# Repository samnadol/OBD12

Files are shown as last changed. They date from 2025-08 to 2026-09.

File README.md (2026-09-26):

# OBD12 — Hardware Handoff

OBD12 is a small OBD-II dongle. It plugs straight into a vehicle's J1962 diagnostic port and bridges the vehicle's **high-speed CAN bus (ISO 15765-4)** to **Bluetooth Low Energy** (BlueNRG-M2SP module) and to a **USB-C serial port** (FT230X). An STM32G431 runs the whole board.

| Item | Location |
|---|---|
| Schematic / PCB (KiCad 9) | `pcb/pcb.kicad_sch` (root), `pcb/usb.kicad_sch`, `pcb/can.kicad_sch`, `pcb/ble.kicad_sch`, `pcb/pcb.kicad_pcb` |
| STM32 firmware (STM32CubeIDE) | `firmware/OBD12/` (`OBD12.ioc` is the CubeMX pin config) |
| BlueNRG-M2SP network-processor image | `firmware/BLUENRG-M2SP_DTM_SPI.hex` |
| Host-side test script (USB serial) | `software/main.py` |

---

## 1. Block diagram

```
                         ┌──────────────────────── +3V3 rail ───────────────────────────┐
                         │                                                              │
 USB-C J2 ──VBUS(5V)──► U4 SPX3819 LDO ──USB_REG_OUT(3.3V)──► U5 LM66100 ─┐             │
    │                                                                     ├──► +3V3 ────┤
    │                                                                     │             │
 OBD J3 pin16 ─► D2 TVS ─► FB1 ─► +12V ─► U7 LM2842 buck ─CAN_REG_OUT(3.3V)─► U8 LM66100 ─┘  │
                                                                                        │
 USB-C D+/D- ─► U2 USBLC6 ESD ─► U3 FT230X ◄──UART 115200──► ┌───────────────┐         │
                                                             │  U1 STM32G431 │◄────────┤
 OBD J3 pin6/14 ─► D1 PESD1CAN ─► U6 TCAN337 ◄──FDCAN1─────► │  32 MHz HSE   │         │
                                                             │               │         │
                                  U9 BlueNRG-M2SP ◄──SPI1───►└───────────────┘         │
                                  (VIN via JP3) ◄───────────────────────────────────────┘
```

---

## 2. Board summary

| Parameter | Value |
|---|---|
| Board outline | ~41.8 × 39.9 mm |
| Layers | 4 layers, 1.6 mm FR4 (0.21 mm prepreg / 1.065 mm core / 0.21 mm prepreg) |
| Layer use | F.Cu signal + local pours (+12V, buck SW, CAN_REG_OUT, GND) · In1.Cu **GND plane** · In2.Cu **power plane** (+3V3 and USB_VBUS areas) · B.Cu signal |
| Passives | 0603 throughout |
| Assembly | Every BOM line has an LCSC part number (built for JLCPCB PCBA) |
| Supply inputs | Vehicle +12 V (OBD pin 16) **or** USB-C 5 V. Either one runs the whole board. |
| Logic level | **3.3 V everywhere.** Nothing on the board runs at 5 V logic. |
| MCU clock | 32 MHz crystal (HSE), SYSCLK = 32 MHz (PLL not used) |
| Regulatory | The BlueNRG-M2SP is a pre-certified module; the silkscreen carries "Contains FCC ID S9NBNRGM2SP" |

---

## 3. Power

### 3.1 Rails

| Net | Nominal | Source | Loads | Notes |
|---|---|---|---|---|
| `+12V` | 9–16 V (vehicle battery) | OBD J3 pin 16 → D2 → FB1 | U7 VIN, U7 EN | 12 V vehicles only (see TVS note). The LM2842 accepts 4.5–42 V. |
| `/usb/USB_VBUS` | 5 V | USB-C J2 VBUS | U4 IN/EN, U3 VCC, U2 VBUS | The CC pins have 5.1 kΩ pulldowns (R8, R9), so the board is a USB-C sink at default USB current. |
| `CAN_REG_OUT` | 3.31 V | U7 LM2842X buck | U8 VIN, MCU PA7 (ADC) | Max 600 mA. |
| `USB_REG_OUT` | 3.33 V | U4 SPX3819M5-L LDO | U5 VIN, U8 ~CE, MCU PA6 (ADC) | Max 500 mA. |
| `+3V3` | ~3.3 V | U5 / U8 ideal-diode OR | MCU, TCAN337, BlueNRG (via JP3), LEDs, pull-ups | LM66100: 1.5 A max, ~141 mΩ Ron. |
| `Net-(U3-3V3OUT)` | 3.3 V | FT230X internal regulator | FT230X VCCIO and ~RESET | Local to U3 only. |

### 3.2 12 V input path (sheet `can`)
- **D2 SMAJ24A**: 400 W unidirectional TVS from OBD pin 16 to GND. It has a 24 V standoff and clamps around 39 V at rated peak current. Because it would start conducting on a 24 V truck's charging voltage, the board is **12 V vehicles only**.
- **FB1 BLM18AG121SN1D**: ferrite bead that filters the input.
- **No series reverse-polarity diode.** OBD pin 16 is always battery positive in a real vehicle. On a bench supply, a reversed connection forward-biases D2 and shorts the supply.
- **U7 LM2842X**: 550 kHz, 600 mA asynchronous buck.
  - Parts: L1 15 µH (Würth WE-LQSH-3012), D3 SM5819PL Schottky catch diode, C19 100 nF bootstrap cap. EN is tied to VIN, so the buck is always on.
  - Feedback divider: R19 3.4 kΩ (top) and R20 1.02 kΩ (bottom).
  - Vout = 0.765 V × (1 + 3.4/1.02) ≈ **3.31 V**.
  - Input caps: C22 100 nF, C23 10 µF. Output caps: C20 10 µF, C21 100 nF.

### 3.3 USB input path (sheet `usb`)
- **U4 SPX3819M5-L** adjustable LDO. EN is tied to VBUS.
  - Divider: R12 56 kΩ (top) and R14 33 kΩ (bottom).
  - Vout = 1.235 V × (1 + 56/33) ≈ **3.33 V**.
  - Input caps: C10 1 µF, C11 100 nF, C12 10 µF.

### 3.4 Power OR-ing / priority (U5, U8 — LM66100 ideal diodes)
- U5 (USB side) and U8 (CAN side) both drive `+3V3`.
- **USB has priority:**
  - `USB_REG_OUT` drives U8 `~CE` directly. When USB power is present, the 12 V path is shut off.
  - U8's `ST` output (net `CAN_REG_ST`, pulled up to `CAN_REG_OUT` by R18 10 kΩ) drives U5 `~CE`.
- Both status pins go to the MCU:
  - `USB_REG_ST` (U5 ST, pulled up to +3V3 by R13 10 kΩ) → **PB6**
  - `CAN_REG_ST` (U8 ST) → **PB7**
- Both regulator outputs are also measured by ADC2: `USB_REG_OUT` → **PA6** (IN3) and `CAN_REG_OUT` → **PA7** (IN4). Firmware reports all four values over BLE (Status → Power characteristic).
- +3V3 bulk and decoupling capacitors:
  - C13 10 µF, C14 100 nF (usb sheet)
  - C16 1 µF, C17 10 µF, C24 10 µF, C25 100 nF (can sheet)
  - MCU decoupling C1–C5

### 3.5 Power indicator
- **DS1** (red, silk "PWR"): +3V3 → DS1 → R5 1.02 kΩ → GND. It stays on whenever +3V3 is up.

---

## 4. STM32G431KBT6 pin map (U1, LQFP-32)

The MCU is an STM32G431KBT6: Cortex-M4F, 128 KB flash, 32 KB RAM, running at 3.3 V.

| Pin | Port | Net (schematic) | Function / peripheral | Dir | Connected to | Notes |
|---|---|---|---|---|---|---|
| 1 | VDD | +3V3 | Supply | – | | C1–C5 decoupling |
| 2 | PF0 | SYS_OSC_IN | RCC_OSC_IN | – | Y1 pin 1, C6 12 pF | 32 MHz HSE |
| 3 | PF1 | SYS_OSC_OUT | RCC_OSC_OUT | – | Y1 pin 3, C7 12 pF | |
| 4 | PG10-NRST | SYS_NRST | Reset | I | R3 10 k pull-up, SW1 to GND, J1 pin 3 | Silk "RESET" |
| 5 | PA0 | SPI_IRQ | GPIO EXTI0 (rising) | I | JP4 → U9 DIO7 | BlueNRG IRQ |
| 6 | PA1 | BLE_NRST | GPIO out | O | U9 RESETN, J5 pin 3 | BlueNRG reset, active low |
| 7 | PA2 | FDCAN_FAULT | GPIO EXTI2 | I | U6 FAULT, R15 10 k pull-up | Transceiver fault, open-drain, active high |
| 8 | PA3 | FDCAN_SILENT | GPIO out | O | U6 S | High = silent (listen-only). Firmware drives it low. |
| 9 | PA4 | HWCONF0 | GPIO in, internal pull-down | I | R1 0 Ω (DNP) to +3V3 | HW strap bit 0 |
| 10 | PA5 | LED_STATUS_1 | GPIO out | O | DS2 anode (green, R6 1.02 k) | Silk "S1", active high |
| 11 | PA6 | USB_REG_OUT | ADC2_IN3 | AI | U4 OUT | USB LDO output monitor |
| 12 | PA7 | CAN_REG_OUT | ADC2_IN4 | AI | U7 buck output | 12 V buck output monitor |
| 13 | PB0 | LED_STATUS_2 | GPIO out | O | DS3 anode (green, R7 1.02 k) | Silk "S2", active high |
| 14 | VSSA | GND | | | | |
| 15 | VDDA | +3V3 | | | | No separate analog filtering |
| 16 | VSS | GND | | | | |
| 17 | VDD | +3V3 | | | | |
| 18 | PA8 | HWCONF1 | GPIO in, internal pull-down | I | R2 0 Ω (DNP) to +3V3 | HW strap bit 1 |
| 19 | PA9 | USB_RXD,MCU_TXD | USART1_TX | O | U3 RXD | 115200 8N1 |
| 20 | PA10 | USB_TXD,MCU_RXD | USART1_RX | I | U3 TXD | |
| 21 | PA11 | FDCAN_RX | FDCAN1_RX | I | U6 RXD | |
| 22 | PA12 | FDCAN_TX | FDCAN1_TX | O | U6 TXD | |
| 23 | PA13 | T_JTMS_SWDIO | SWDIO | IO | J1 pin 2 | |
| 24 | PA14 | T_JCLK_SWCLK | SWCLK | I | J1 pin 4 | |
| 25 | PA15 | SPI_CS | GPIO out (SPI1 CS) | O | U9 DIO11 | Active low |
| 26 | PB3 | SPI_CLK | SPI1_SCK | O | U9 DIO0 | |
| 27 | PB4 | SPI_MISO | SPI1_MISO | I | U9 DIO2 | |
| 28 | PB5 | SPI_MOSI | SPI1_MOSI | O | U9 DIO3 | |
| 29 | PB6 | USB_REG_ST | GPIO in | I | U5 ST, R13 10 k pull-up | USB-path ideal diode status |
| 30 | PB7 | CAN_REG_ST | GPIO in | I | U8 ST, U5 ~CE, R18 10 k pull-up to CAN_REG_OUT | CAN-path ideal diode status |
| 31 | PB8-BOOT0 | SYS_BOOT0 | BOOT0 | I | R4 10 k pull-down, JP1 to +3V3 | Bridge JP1 to boot the ST ROM bootloader |
| 32 | VSS | GND | | | | |

### Peripheral configuration (from `OBD12.ioc`)

| Peripheral | Settings |
|---|---|
| RCC | HSE 32 MHz crystal → SYSCLK / AHB / APB = 32 MHz. FDCAN kernel clock = HSE. |
| FDCAN1 | Classic CAN, **500 kbit/s**. Prescaler 1, Seg1 50, Seg2 13 (64 tq, sample point ≈ 79.7 %), SJW 4. Auto-retransmit off. One standard-ID range filter (0x000–0x7FF → FIFO0). |
| SPI1 | Master, 8-bit, CPOL low / CPHA 2nd edge (mode 1), prescaler 16 → 2 Mbit/s |
| USART1 | 115200 baud, 8N1, async |
| ADC2 | 12-bit, single-ended, software trigger, IN3 / IN4 |
| TIM6 / TIM7 | 1 kHz tick base (32000 prescaler). TIM6 period 1000 (1 s), TIM7 period 100 (100 ms). |
| EXTI | EXTI0 (BLE IRQ), EXTI2 (CAN fault) |

### Hardware configuration straps
- R1 (PA4 → HWCONF0) and R2 (PA8 → HWCONF1) are 0 Ω links to +3V3. Both are **DNP** by default, and the internal pull-downs read the strap as `0b00`.
- Firmware prints the strap at boot (`Hardware Configuration: 0bXY`). Silkscreen: "CONF 0 1".
- Use the straps to mark board revisions or assembly variants.

---

## 5. CAN interface (sheet `can`)

| Item | Detail |
|---|---|
| Transceiver | **U6 TCAN337** (TI), SOIC-8, 3.3 V supply (VCC = +3V3), up to 1 Mbit/s. Pin 5 = FAULT, pin 8 = S (silent). |
| Logic side | TXD/RXD at 3.3 V directly on PA12/PA11. No level shifting is needed. |
| Bus levels | ISO 11898-2 compatible. The differential is ~0 V when recessive and ≥ 1.5 V when dominant into 60 Ω. A 3.3 V transceiver works on the same bus as 5 V transceivers. |
| Bit rate | 500 kbit/s in firmware (standard OBD-II CAN rate). The hardware supports up to 1 Mbit/s classic CAN. |
| Modes | PA3 low = normal. PA3 high = silent/listen-only (TX disabled, RX still active). |
| Fault | FAULT is open-drain, pulled up by R15 10 k to +3V3, and raises EXTI2 on PA2. It flags TXD dominant timeout, thermal shutdown, and similar faults. |
| ESD | **D1 PESD1CAN**: dual-line CAN ESD/TVS (Nexperia) on CANH/CANL to GND |
| Termination | **None populated (DNP).** Optional split termination: R16 60 Ω + R17 60 Ω in series across CANH–CANL, with C18 4.7 nF from the midpoint to GND. |
| Connector pins | CANH → J3 pin 6, CANL → J3 pin 14 |

**Termination guidance**
- **In a vehicle: leave R16, R17, and C18 unpopulated.** The OBD port is a stub off an already-terminated bus (two 120 Ω ends = 60 Ω). Adding a third terminator loads the bus.
- **On the bench** with only one other node: fit R16/R17 (60 Ω; 60.4 Ω 1 % is fine) and C18 4.7 nF to get split termination. The other end still needs its own 120 Ω.
- Measure CANH–CANL with the vehicle off. You should see ~60 Ω from the vehicle side alone.

### OBD-II connector (J3, Comtech C-OBD-II-16M, male J1962 plug)

| J3 pin | Standard use | Board net | Connected? |
|---|---|---|---|
| 2 | SAE J1850 bus + | `OBD_J1850+` | Labelled only, no circuitry |
| 4 | Chassis ground | `OBD_CGND` → J4 pin 1 | Only through **J4 (DNP)**. Fit a jumper/short on J4 to tie chassis GND to board GND. |
| 5 | Signal ground | GND | Yes (board ground reference) |
| 6 | CAN high (ISO 15765) | `CAN_T+` | Yes → U6 CANH |
| 7 | ISO 9141/14230 K-line | `OBD_1941-2K` | Labelled only, no circuitry |
| 10 | SAE J1850 bus − | `OBD_J1850-` | Labelled only, no circuitry |
| 14 | CAN low (ISO 15765) | `CAN_T-` | Yes → U6 CANL |
| 15 | ISO 9141/14230 L-line | `OBD_1941-2L` | Labelled only, no circuitry |
| 16 | Battery + (unswitched) | +12V (via D2/FB1) | Yes |
| 1, 3, 8, 9, 11, 12, 13 | OEM-specific | – | Not connected |

Only CAN (ISO 15765-4) is implemented. The J1850, K-line, and L-line pins are broken out to named nets for a future revision.

---

## 6. Bluetooth LE (sheet `ble`)

| Item | Detail |
|---|---|
| Module | **U9 ST BlueNRG-M2SP**: BlueNRG-2 SoC with integrated chip antenna, pre-certified, used as an SPI network processor |
| Firmware on module | `firmware/BLUENRG-M2SP_DTM_SPI.hex` (ST DTM image, SPI transport). Flash it once through J5. |
| Supply | VIN from +3V3 through **JP3 "BLE_3V3_ISO"** (solder jumper, bridged by default). Decoupling: C26 100 nF, C27 1 µF, C28 10 µF. Cut JP3 to isolate or measure module current. |
| Host link | SPI1 at 2 Mbit/s, mode 1 |

**MCU ↔ module wiring**

| Signal | STM32 | BlueNRG-M2SP |
|---|---|---|
| SPI_CLK | PB3 | DIO0 (pin 15) |
| SPI_MISO | PB4 | DIO2 (pin 16) |
| SPI_MOSI | PB5 | DIO3 (pin 17) |
| SPI_CS | PA15 | DIO11 (pin 11) |
| SPI_IRQ | PA0 | DIO7/BOOT (pin 7), through JP4 |
| RESET | PA1 | RESETN (pin 19) |
| SWDIO / SWCLK | – | DIO10 (pin 13) / DIO9 (pin 12) → J5 |

**Boot / IRQ jumpers.** DIO7 is both the module's SPI IRQ output and its bootloader-select pin.

| Jumper | Silk | Default | Purpose |
|---|---|---|---|
| JP4 | BLE BOOT ISO | Bridged | Connects DIO7 to MCU PA0 (normal operation) |
| JP2 | BLE_BOOT 1 | Open | Ties DIO7 to +3V3 (force the module's bootloader at reset) |
| JP5 | BLE_BOOT 0 | Open | Ties DIO7 to GND |
| JP3 | BLE_3V3_ISO | Bridged | Module VIN from +3V3 |

**Firmware BLE profile (for reference).** The module advertises at 250–500 ms intervals (0.625 ms units: 400–800) and exposes three services:
- Device Information
- Nordic-UART-style RX/TX service
- Status service with a Power characteristic carrying the regulator ST bits and ADC readings

---

## 7. USB-C / debug UART (sheet `usb`)

| Item | Detail |
|---|---|
| Connector | **J2** USB-C receptacle (G-Switch GT-USB-7010ASV), USB 2.0 only |
| CC | R8, R9 5.1 kΩ to GND on CC1 and CC2 → default-current sink |
| ESD | **U2 USBLC6-2SC6** on D+/D−, VBUS-referenced |
| Bridge | **U3 FTDI FT230XS**. VCC = VBUS (5 V). The internal 3V3OUT feeds VCCIO, so the UART is **3.3 V**. RTS is looped to CTS. |
| UART | FT230X TXD → PA10 (USART1_RX) and PA9 (USART1_TX) → FT230X RXD, 115200 8N1 |
| LEDs | DS4 (RX) on CBUS1 and DS5 (TX) on CBUS2, both green. Each LED is fed from +3V3 through R10/R11 60 Ω, with the cathode sunk by CBUS. Silk "TX RX". |
| USB IDs | VID 0x0403 / PID 0x6015 (FT230X default). `software/main.py` finds the board by an FTDI serial number starting with `OBD12_`, so **program each FT230X EEPROM with FT_PROG** to set that serial. |

FT230X decoupling: C8 100 nF + C9 1 µF on 3V3OUT, C10–C12 on VBUS.

---

## 8. Programming & debug connectors

Both programming headers are Tag-Connect **TC2030-NL** (no-legs) footprints and use a TC2030-NL cable with a standard 10-pin Cortex adapter.

| Ref | Target | Pin 1 | Pin 2 | Pin 3 | Pin 4 | Pin 5 | Pin 6 |
|---|---|---|---|---|---|---|---|
| J1 | STM32 (U1) | +3V3 (VTref) | SWDIO (PA13) | NRST | SWCLK (PA14) | GND | SWO (NC) |
| J5 | BlueNRG-M2SP (U9) | +3V3 | DIO10 (SWDIO) | RESETN (shared with PA1) | DIO9 (SWCLK) | GND | NC |

**The board must be powered (USB or 12 V) while programming.** Pin 1 is a voltage reference, not a supply input.

Other user controls:
- **SW1** (silk "RESET"): tactile switch that pulls the STM32 NRST low.
- **JP1** (silk "BOOT0 PB8"): open solder jumper. Bridge it to hold BOOT0 high and enter the STM32 system bootloader (USART1 is reachable through the FT230X).

---

## 9. LEDs

| Ref | Colour | Silk | Driven by | Series R | Meaning |
|---|---|---|---|---|---|
| DS1 | Red | PWR | +3V3 | R5 1.02 k | +3V3 present |
| DS2 | Green | S1 | PA5, active high | R6 1.02 k | Firmware status 1 (heartbeat / app state) |
| DS3 | Green | S2 | PB0, active high | R7 1.02 k | Firmware status 2 |
| DS4 | Green | RX | FT230X CBUS1, active low | R10 60 Ω | USB UART RX activity |
| DS5 | Green | TX | FT230X CBUS2, active low | R11 60 Ω | USB UART TX activity |

---

## 10. Bill of materials

This is the populated BOM, generated from the schematic. LCSC numbers come from the `LCSC` field.

| Refs | Qty | Value / part | Package | LCSC | Description |
|---|---|---|---|---|---|
| U1 | 1 | STM32G431KBT6 | LQFP-32 | C5270317 | MCU, Cortex-M4F, 128 KB / 32 KB |
| U2 | 1 | USBLC6-2SC6 | SOT-23-6 | C7519 | USB ESD protection |
| U3 | 1 | FT230XS | SSOP-16 | C69082 | USB ↔ UART bridge |
| U4 | 1 | SPX3819M5-L | SOT-23-5 | C9056 | 500 mA adjustable LDO (USB → 3.3 V) |
| U5, U8 | 2 | LM66100DCK | SC-70-6 | C2869734 | Ideal diode (power OR-ing) |
| U6 | 1 | TCAN337 | SOIC-8 | C2860648 | 3.3 V CAN transceiver with silent mode and fault output |
| U7 | 1 | LM2842X | TSOT-23-6 | C2865947 | 42 V / 600 mA buck (12 V → 3.3 V) |
| U9 | 1 | BLUENRG-M2SP | module | C1850403 | BLE 5 module (SPI) |
| Y1 | 1 | Würth 830103622909 | 3225-4 | C9009 | Crystal (32 MHz HSE per firmware config) |
| D1 | 1 | PESD1CAN | SOT-23 | C15771 | CAN bus ESD |
| D2 | 1 | SMAJ24A | SMA | C113962 | 24 V TVS on +12 V input |
| D3 | 1 | SM5819PL-TP | SOD-123F | C669023 | Buck catch Schottky |
| L1 | 1 | 15 µH WE-LQSH-3012 | 3×3 mm | C668450 | Buck inductor |
| FB1 | 1 | BLM18AG121SN1D | 0603 | C76892 | Ferrite bead, 12 V input |
| J2 | 1 | USB-C 16P (GT-USB-7010ASV) | SMD | C2988369 | USB 2.0 Type-C receptacle |
| J3 | 1 | Comtech C-OBD-II-16M | – | – | OBD-II J1962 male plug |
| J1, J5 | 2 | TC2030-NL | footprint | – | SWD Tag-Connect pads (no part) |
| SW1 | 1 | TS-1187A | SMD | C318884 | Reset button |
| DS1 | 1 | Red LED | 0603 | C965799 | Power |
| DS2–DS5 | 4 | Green LED | 0603 | C965804 | Status / USB activity |
| C2–C4, C8, C11, C14, C15, C19, C21, C22, C25, C26 | 12 | 100 nF | 0603 | C14663 | Decoupling / bootstrap |
| C1, C9, C10, C16, C27 | 5 | 1 µF | 0603 | C559769 | Decoupling |
| C5, C12, C13, C17, C20, C23, C24, C28 | 8 | 10 µF | 0603 | C92487 | Bulk |
| C6, C7 | 2 | 12 pF | 0603 | C107034 | Crystal load |
| R3, R4, R13, R15, R18 | 5 | 10 k | 0603 | C25804 | Pull-ups / pull-downs |
| R5–R7, R20 | 4 | 1.02 k | 0603 | C22831 | LED resistors, buck FB bottom |
| R8, R9 | 2 | 5.1 k | 0603 | C23186 | USB-C CC pulldowns |
| R10, R11 | 2 | 60 Ω | 0603 | C166918 | FT230X LED resistors |
| R12 | 1 | 56 k | 0603 | C23206 | LDO ADJ top |
| R14 | 1 | 33 k | 0603 | C4216 | LDO ADJ bottom |
| R19 | 1 | 3.4 k | 0603 | C22997 | Buck FB top |
| JP1–JP5 | 5 | Solder jumpers | – | – | JP3 and JP4 bridged by default; JP1, JP2, JP5 open |
| G1 | 1 | Logo | – | – | Silkscreen |

**DNP (do not populate) by default**

| Ref | Value | Purpose |
|---|---|---|
| R1, R2 | 0 Ω | HWCONF0/1 straps |
| R16, R17 | 60 Ω | CAN split termination |
| C18 | 4.7 nF | CAN split-termination midpoint cap |
| J4 | 1×2 2.54 mm header | Links OBD chassis ground (pin 4) to board GND |

---

## 11. Bring-up checklist

1. **Power, USB only.**
   - `USB_REG_OUT` ≈ 3.33 V and `+3V3` ≈ 3.3 V. DS1 lights.
   - FT230X enumerates (0403:6015).
2. **Power, 12 V only** (current-limited bench supply on J3 pins 16 and 5):
   - `CAN_REG_OUT` ≈ 3.31 V and `+3V3` up.
   - Check the buck switch node `/can/SW` for clean 550 kHz switching.
3. **Both supplies connected.**
   - `+3V3` must stay up with no glitch when either source is added or removed.
   - PB6/PB7 read back the expected status. See review note 2 below.
4. **Program the STM32** over J1 (SWD) and program the **BlueNRG-M2SP** over J5 with `BLUENRG-M2SP_DTM_SPI.hex`.
5. **Program the FT230X EEPROM** so its serial number starts with `OBD12_`.
6. **Check the UART console** at 115200 8N1. The boot banner shows the HWCONF strap and the STM32 UID.
7. **Check CAN.**
   - On the bench, fit the termination or use a terminated CAN adapter at 500 kbit/s.
   - In a vehicle, the firmware requests the VIN (Mode 09 PID 02) at start-up.
   - PA2 FAULT must stay low.
8. **Check BLE.** The module advertises, and the Nordic UART and Status services are visible from a phone.

---

## 12. Design review notes / open items

These came up while documenting the design. **Check each one before the next spin.**

1. **U4 SPX3819 has no output capacitor on `USB_REG_OUT`.**
   - The LDO needs ≥ 1 µF on its output to be stable.
   - The 10 µF parts (C13, C17, C24) sit on `+3V3`, *behind* the LM66100 ideal diode.
   - Add ~1–10 µF directly on `USB_REG_OUT`. The buck side already has C20/C21.
2. **Power-priority logic depends on the LM66100 `ST` polarity.**
   - With USB present, U8 is disabled, and U5's `~CE` is driven by U8's `ST` pin (pulled up to `CAN_REG_OUT` by R18).
   - If `ST` goes high-Z while U8 is disabled, R18 pulls U5 `~CE` high and **both paths turn off when USB and 12 V are both present.**
   - Verify on hardware (checklist step 3) and against the LM66100 datasheet.
3. **ADC monitoring of the 3.3 V rails.**
   - `USB_REG_OUT` and `CAN_REG_OUT` (~3.31–3.33 V) go straight to PA6/PA7 while VDDA = `+3V3`, which is slightly lower after the ideal-diode drop.
   - The readings will sit at or near full scale (4095), so they only work as presence detectors.
   - Add a divider (for example 2:1) if real voltage measurement is wanted. The ADC pin also sees more than VDDA when that rail is backed by the other source.
4. **Voltage rating of C23 (10 µF, 0603, LCSC C92487) on the +12 V rail.**
   - Confirm the rated voltage is at least 25 V, and preferably 50 V, for automotive transients up to the TVS clamp (~39 V).
   - Also account for DC-bias derating: a 0603 10 µF part at 12 V keeps only a small fraction of its nominal capacitance.
   - C22 (100 nF, C14663) is 50 V.
5. **FT230X LED resistors R10/R11 = 60 Ω.**
   - That gives roughly 15–20 mA per LED, above the FT230X CBUS default drive strength.
   - Consider ~1 k, or configure CBUS drive in the EEPROM.
6. **FT230X back-powering.** When the board runs on 12 V only, the MCU's TX (PA9) drives the RXD pin of the unpowered FT230X. A series resistor on PA9 would limit that current.
7. **U9 pad 21 (GND) shows as unconnected in the netlist.** Only pad 8 is tied to GND. Check the footprint against the BlueNRG-M2SP datasheet and ground every GND pad.
8. **No reverse-polarity protection on the 12 V input.** This is acceptable for a J1962 port but not for a bench supply. A series Schottky or a P-FET would protect it.
9. **VDDA is tied directly to +3V3.** There is no ferrite or RC filter, which is acceptable for the current coarse ADC use.
10. Items carried over from the previous README:
    - Add an activity/status LED for the BlueNRG-M2SP, driven by the DTM firmware.
    - Add 10–100 k pull-down resistors on each regulator output so the outputs don't float when that source is unpowered. This partly overlaps item 1. `USB_REG_OUT` already has R12+R14 (89 k).
    - Future: move from the M2SP module to a bare BlueNRG-2 with a direct antenna.

### Firmware TODO (carried over)
- CAN peripheral enable and setup. The FDCAN init, filter, and RX path now exist in `Core/Src/CAN/`.
- OBD layer (`Core/Src/CAN/OBD.c`, `ISOTP.c`)
- BLE and UART transport layers
- App protocol layer

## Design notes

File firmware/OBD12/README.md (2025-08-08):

TX Power Settings:
	 0: -14 dBm
	 1: -11 dBm
	 2: -8 dBm
	 3: -5 dBm
	 4: -2 dBm
	 5: 2 dBm
	 6: 4 dBm
	 7: 8 dBm

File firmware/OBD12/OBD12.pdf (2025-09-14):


19/08/2025

OBD12 Project
Configuration Report

## 1. Description

### 1.1. Project

Project Name | OBD12
Board Name | custom
Generated with: | STM32CubeMX 6.15.0
Date | 08/19/2025

### 1.2. MCU

MCU Series | STM32G4
MCU Line | STM32G4x1
MCU name | STM32G431KBTx
MCU Package | LQFP32
MCU Pin number | 32

### 1.3. Core(s) information

Core(s) | ARM Cortex-M4

## 2. Pinout Configuration

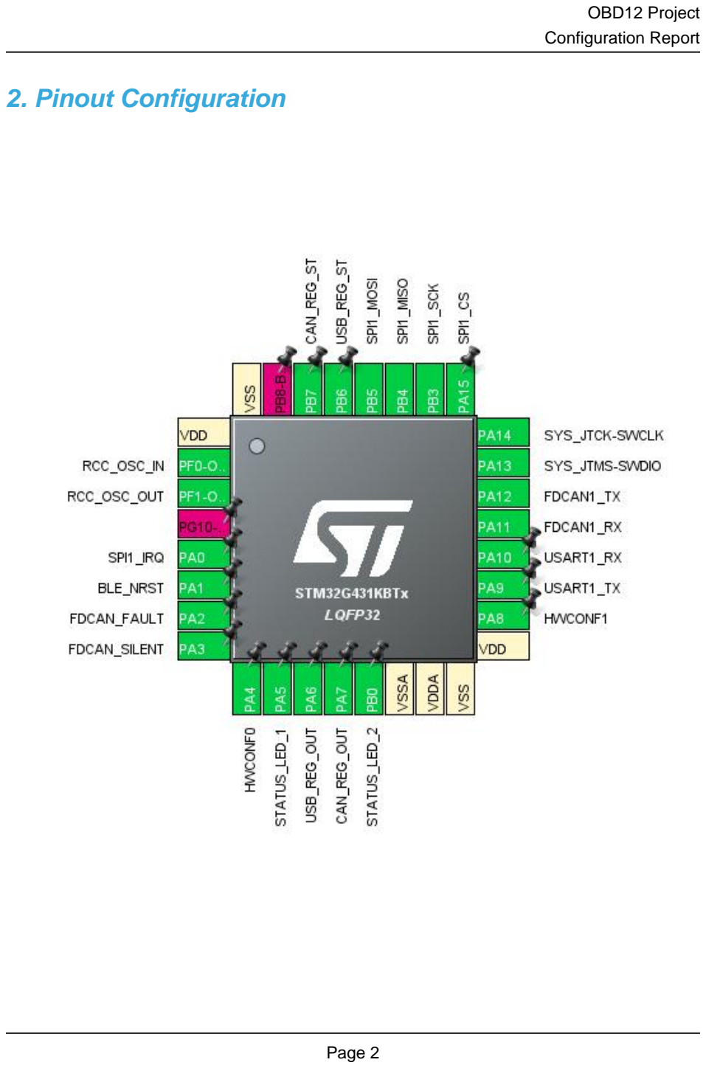
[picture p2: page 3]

## 3. Pins Configuration

Pin Number LQFP32 | Pin Name (function after reset) | Pin Type | Alternate Function(s) | Label
1 | VDD | Power
2 | PF0-OSC_IN | I/O | RCC_OSC_IN
3 | PF1-OSC_OUT | I/O | RCC_OSC_OUT
4 | PG10-NRST | I/O
5 | PA0 | I/O | GPIO_EXTI0 | SPI1_IRQ
6 | PA1 * | I/O | GPIO_Output | BLE_NRST
7 | PA2 | I/O | GPIO_EXTI2 | FDCAN_FAULT
8 | PA3 * | I/O | GPIO_Output | FDCAN_SILENT
9 | PA4 * | I/O | GPIO_Input | HWCONF0
10 | PA5 * | I/O | GPIO_Output | STATUS_LED_1
11 | PA6 | I/O | ADC2_IN3 | USB_REG_OUT
12 | PA7 | I/O | ADC2_IN4 | CAN_REG_OUT
13 | PB0 * | I/O | GPIO_Output | STATUS_LED_2
14 | VSSA | Power
15 | VDDA | Power
16 | VSS | Power
17 | VDD | Power
18 | PA8 * | I/O | GPIO_Input | HWCONF1
19 | PA9 | I/O | USART1_TX
20 | PA10 | I/O | USART1_RX
21 | PA11 | I/O | FDCAN1_RX
22 | PA12 | I/O | FDCAN1_TX
23 | PA13 | I/O | SYS_JTMS-SWDIO
24 | PA14 | I/O | SYS_JTCK-SWCLK
25 | PA15 * | I/O | GPIO_Output | SPI1_CS
26 | PB3 | I/O | SPI1_SCK
27 | PB4 | I/O | SPI1_MISO
28 | PB5 | I/O | SPI1_MOSI
29 | PB6 * | I/O | GPIO_Input | USB_REG_ST
30 | PB7 * | I/O | GPIO_Input | CAN_REG_ST
31 | PB8-BOOT0 | I/O
32 | VSS | Power

* The pin is affected with an I/O function

## 4. Clock Tree Configuration

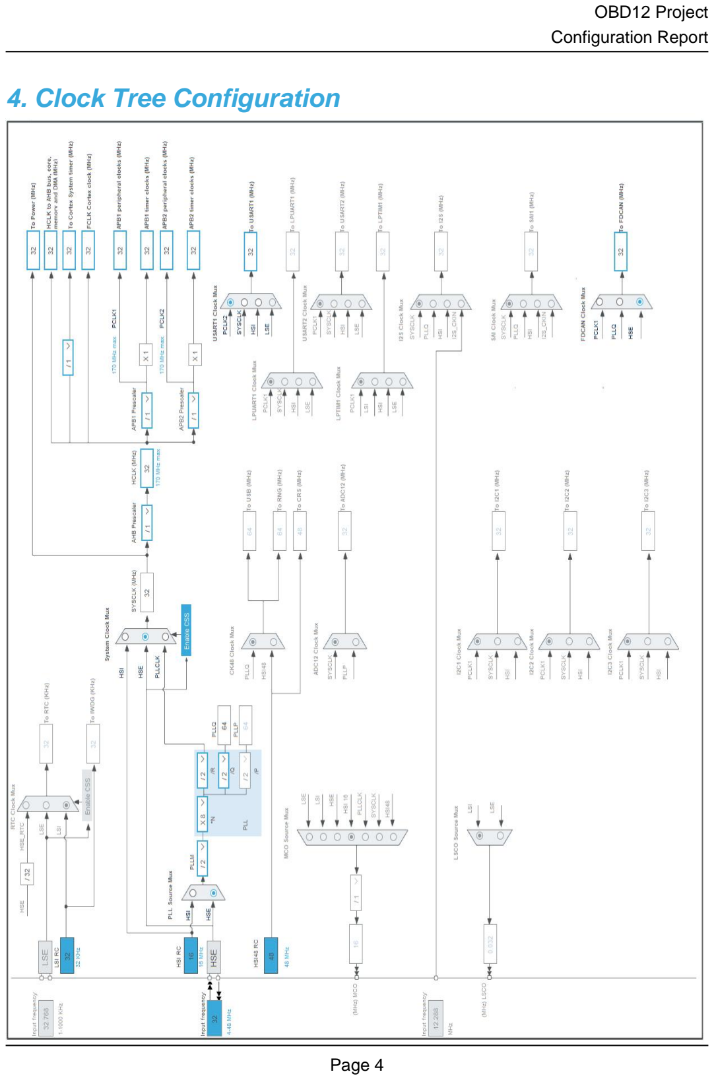
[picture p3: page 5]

## 1. Power Consumption Calculator report

### 1.1. Microcontroller Selection

Series | STM32G4
Line | STM32G4x1
MCU | STM32G431KBTx
Datasheet | DS12589_Rev0

### 1.2. Parameter Selection

Temperature | 25
Vdd | 3.0

### 1.3. Battery Selection

Battery | Li-SOCL2(A3400)
Capacity | 3400.0 mAh
Self Discharge | 0.08 %/month
Nominal Voltage | 3.6 V
Max Cont Current | 100.0 mA
Max Pulse Current | 200.0 mA
Cells in series | 1
Cells in parallel | 1

### 1.4. Sequence

Step | Step1 | Step2
Mode | RUN | STOP1
Vdd | 3.0 | 3.0
Voltage Source | Battery | Battery
Range | Range1-Boost | NoRange
Fetch Type | FLASH/ART | NA
CPU Frequency | 170 MHz | 0 Hz
Clock Configuration | HSE BYP PLL | ALL CLOCKS OFF
Clock Source Frequency | 4 MHz | 0 Hz
Peripherals
Additional Cons. | 0 mA | 0 mA
Average Current | 25.5 mA | 59 µA
Duration | 0.1 ms | 0.9 ms
DMIPS | 213.0 | 0.0
Ta Max | 124.19 | 129.99
Category | In DS Table | In DS Table

### 1.5. Results

Sequence Time | 1 ms | Average Current | 2.6 mA
Battery Life | 1 month, 23 days, 22 hours | Average DMIPS | 212.5 DMIPS

### 1.6. Chart

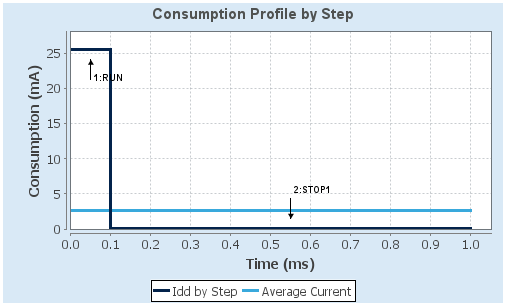
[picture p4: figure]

## 2. Software Project

### 2.1. Project Settings

Name | Value
Project Name | OBD12
Project Folder | C:\Users\samna\Desktop\OBD12\firmware\OBD12
Toolchain / IDE | STM32CubeIDE
Firmware Package Name and Version | STM32Cube FW_G4 V1.6.1
Application Structure | Advanced
Generate Under Root | Yes
Do not generate the main() | No
Minimum Heap Size | 0x200
Minimum Stack Size | 0x400

### 2.2. Code Generation Settings

Name | Value
STM32Cube MCU packages and embedded software | Copy only the necessary library files
Generate peripheral initialization as a pair of '.c/.h' files | No
Backup previously generated files when re-generating | No
Keep User Code when re-generating | Yes
Delete previously generated files when not re-generated | Yes
Set all free pins as analog (to optimize the power consumption) | No
Enable Full Assert | No

### 2.3. Advanced Settings - Generated Function Calls

Rank | Function Name | Peripheral Instance Name
1 | SystemClock_Config | RCC
2 | MX_GPIO_Init | GPIO
3 | MX_ADC2_Init | ADC2
4 | MX_USART1_UART_Init | USART1
5 | MX_FDCAN1_Init | FDCAN1
6 | MX_TIM6_Init | TIM6
7 | MX_TIM7_Init | TIM7

## 3. Peripherals and Middlewares Configuration

### 3.1. ADC2

IN3: IN3 Single-ended
mode: IN4
3.1.1. Parameter Settings:

ADCs_Common_Settings:

Mode | Independent mode
ADC_Settings:
Clock Prescaler | Synchronous clock mode divided by 2
Resolution | ADC 12-bit resolution
Data Alignment | Right alignment
Gain Compensation | 0
Scan Conversion Mode | Disabled
End Of Conversion Selection | End of single conversion
Low Power Auto Wait | Disabled
Continuous Conversion Mode | Disabled
Discontinuous Conversion Mode | Disabled
DMA Continuous Requests | Disabled
Overrun behaviour | Overrun data preserved
ADC_Regular_ConversionMode:
Enable Regular Conversions | Enable
Enable Regular Oversampling | Disable
Number Of Conversion | 1
External Trigger Conversion Source | Regular Conversion launched by software
External Trigger Conversion Edge | None
Rank | 1
Channel | Channel 3
Sampling Time | 2.5 Cycles
Offset Number | No offset
ADC_Injected_ConversionMode:
Enable Injected Conversions | Disable
Analog Watchdog 1:
Enable Analog WatchDog1 Mode | false
Analog Watchdog 2:
Enable Analog WatchDog2 Mode | false
Analog Watchdog 3:
Enable Analog WatchDog3 Mode | false

### 3.2. FDCAN1

mode: Activated
3.2.1. Parameter Settings:

Basic Parameters:

Clock Divider | Divide kernel clock by 1
Frame Format | Classic mode
Mode | Normal mode
Auto Retransmission | Disable
Transmit Pause | Disable
Protocol Exception | Disable
Nominal Sync Jump Width | 4 *
Data Prescaler | 1
Data Sync Jump Width | 1
Data Time Seg1 | 1
Data Time Seg2 | 1
Std Filters Nbr | 1 *
Ext Filters Nbr | 0
Tx Fifo Queue Mode | FIFO mode
Bit Timings Parameters:
Nominal Prescaler | 1 *
Nominal Time Quantum | 31.25 *
Nominal Time Seg1 | 50 *
Nominal Time Seg2 | 13 *
Nominal Time for one Bit | 2000 *
Nominal Baud Rate | 500000 *

### 3.3. RCC

High Speed Clock (HSE): Crystal/Ceramic Resonator
3.3.1. Parameter Settings:

System Parameters:

VDD voltage (V) | 3.3
Instruction Cache | Enabled
Prefetch Buffer | Disabled

Data Cache | Enabled
Flash Latency(WS) | 1 WS (2 CPU cycle)
RCC Parameters:
HSI Calibration Value | 64
HSE Startup Timout Value (ms) | 100
LSE Startup Timout Value (ms) | 5000
Power Parameters:
Power Regulator Voltage Scale | Power Regulator Voltage Scale 1
Peripherals Clock Configuration:
Generate the peripherals clock configuration | TRUE

### 3.4. SPI1

Mode: Full-Duplex Master
3.4.1. Parameter Settings:

Basic Parameters:

Frame Format | Motorola
Data Size | 8 Bits *
First Bit | MSB First
Clock Parameters:
Prescaler (for Baud Rate) | 16 *
Baud Rate | 2.0 MBits/s *
Clock Polarity (CPOL) | Low
Clock Phase (CPHA) | 2 Edge *
Advanced Parameters:
CRC Calculation | Disabled
NSS Signal Type | Software

### 3.5. SYS

Debug: Serial Wire
Timebase Source: SysTick
mode: save power of non-active UCPD - deactive Dead Battery pull-up

### 3.6. TIM6

mode: Activated

3.6.1. Parameter Settings:

Counter Settings:

Prescaler (PSC - 16 bits value) | 32000 - 1 *
Counter Mode | Up
Dithering | Disable
Counter Period (AutoReload Register - 16 bits value ) | 1000 - 1 *
auto-reload preload | Disable
Trigger Output (TRGO) Parameters:
Trigger Event Selection | Reset (UG bit from TIMx_EGR)

### 3.7. TIM7

mode: Activated
3.7.1. Parameter Settings:

Counter Settings:

Prescaler (PSC - 16 bits value) | 32000 - 1 *
Counter Mode | Up
Dithering | Disable
Counter Period (AutoReload Register - 16 bits value ) | 100 - 1 *
auto-reload preload | Disable
Trigger Output (TRGO) Parameters:
Trigger Event Selection | Reset (UG bit from TIMx_EGR)

### 3.8. USART1

Mode: Asynchronous
3.8.1. Parameter Settings:

Basic Parameters:

Baud Rate | 115200
Word Length | 8 Bits (including Parity)
Parity | None
Stop Bits | 1
Advanced Parameters:
Data Direction | Receive and Transmit
Over Sampling | 16 Samples

Single Sample | Disable
ClockPrescaler | 1
Fifo Mode | Disable
Txfifo Threshold | 1 eighth full configuration
Rxfifo Threshold | 1 eighth full configuration
Advanced Features:
Auto Baudrate | Disable
TX Pin Active Level Inversion | Disable
RX Pin Active Level Inversion | Disable
Data Inversion | Disable
TX and RX Pins Swapping | Disable
Overrun | Enable
DMA on RX Error | Enable
MSB First | Disable

### 3.9. STMicroelectronics.X-CUBE-BLE2.3.3.0

mode: WirelessJjBlueNRGAa2
3.9.1. Parameter Settings:

Log & Debug:
BLE2_DEBUG | 1: Only User messages are shown *
PRINT_CSV_FORMAT | 0: .csv format message print disabled
BLUENRG2_DEBUG | 0: No debug message
Basic Parameters:
HCI_READ_PACKET_SIZE | 128
HCI_MAX_PAYLOAD_SIZE | 128
HCI_READ_PACKET_NUM_MAX | 10
Connection Parameters (for expert users):
Scan Interval (SCAN_P) | 16384
Scan Window (SCAN_L) | 16384
Supervision Timeout (SUPERV_TIMEOUT) | 60
Min Connection Period (CONN_P1) | 40
Max Connection Period (CONN_P2) | 40
Min Connection Length (CONN_L1) | 2000
Max Connection Length (CONN_L2) | 2000
Advertising Type (ADV_DATA_TYPE) | Connectable Undirected Advertising (ADV_IND)
Min Advertising Interval (ADV_INTERV_MIN) | 400 *
Max Advertising Interval (ADV_INTERV_MAX) | 800 *

Min Connection Event Interval (L2CAP_INTERV_MIN) | 9
Max Connection Event Interval (L2CAP_INTERV_MAX) | 20
Timeout Multiplier (L2CAP_TIMEOUT_MULTIPLIER) | 600
3.9.2. Platform Settings:
Exti Line | PA0
BUS IO driver | SPI1
CS Line | PA15
Reset Line | PA1

* User modified value

## 4. System Configuration

### 4.1. GPIO configuration

IP | Pin | Signal | GPIO mode | GPIO pull/up pull down | Max Speed | User Label
ADC2 | PA6 | ADC2_IN3 | Analog mode | Pull-down * | n/a | USB_REG_OUT
| PA7 | ADC2_IN4 | Analog mode | Pull-down * | n/a | CAN_REG_OUT
FDCAN1 | PA11 | FDCAN1_RX | Alternate Function Push Pull | No pull-up and no pull-down | High *
| PA12 | FDCAN1_TX | Alternate Function Push Pull | No pull-up and no pull-down | High *
RCC | PF0-OSC_IN | RCC_OSC_IN | n/a | n/a | n/a
| PF1-OSC_OUT | RCC_OSC_OUT | n/a | n/a | n/a
SPI1 | PB3 | SPI1_SCK | Alternate Function Push Pull | No pull-up and no pull-down | Medium *
| PB4 | SPI1_MISO | Alternate Function Push Pull | No pull-up and no pull-down | Medium *
| PB5 | SPI1_MOSI | Alternate Function Push Pull | No pull-up and no pull-down | Medium *
SYS | PA13 | SYS_JTMS-SWDIO | n/a | n/a | n/a
| PA14 | SYS_JTCK-SWCLK | n/a | n/a | n/a
USART1 | PA9 | USART1_TX | Alternate Function Push Pull | No pull-up and no pull-down | Medium *
| PA10 | USART1_RX | Alternate Function Push Pull | No pull-up and no pull-down | Medium *
GPIO | PA0 | GPIO_EXTI0 | External Interrupt Mode with Rising edge trigger detection | No pull-up and no pull-down | n/a | SPI1_IRQ
| PA1 | GPIO_Output | Output Push Pull | No pull-up and no pull-down | Low | BLE_NRST
| PA2 | GPIO_EXTI2 | External Interrupt Mode with Rising edge trigger detection | No pull-up and no pull-down | n/a | FDCAN_FAULT
| PA3 | GPIO_Output | Output Push Pull | No pull-up and no pull-down | Low | FDCAN_SILENT
| PA4 | GPIO_Input | Input mode | Pull-down * | n/a | HWCONF0
| PA5 | GPIO_Output | Output Push Pull | No pull-up and no pull-down | Low | STATUS_LED_1
| PB0 | GPIO_Output | Output Push Pull | No pull-up and no pull-down | Low | STATUS_LED_2
| PA8 | GPIO_Input | Input mode | Pull-down * | n/a | HWCONF1
| PA15 | GPIO_Output | Output Push Pull | No pull-up and no pull-down | Low | SPI1_CS
| PB6 | GPIO_Input | Input mode | No pull-up and no pull-down | n/a | USB_REG_ST
| PB7 | GPIO_Input | Input mode | No pull-up and no pull-down | n/a | CAN_REG_ST

### 4.2. DMA configuration

nothing configured in DMA service

### 4.3. NVIC configuration

4.3.1. NVIC
Interrupt Table | Enable | Preenmption Priority | SubPriority
Non maskable interrupt | true | 0 | 0
Hard fault interrupt | true | 0 | 0
Memory management fault | true | 0 | 0
Prefetch fault, memory access fault | true | 0 | 0
Undefined instruction or illegal state | true | 0 | 0
System service call via SWI instruction | true | 0 | 0
Debug monitor | true | 0 | 0
Pendable request for system service | true | 0 | 0
System tick timer | true | 0 | 0
EXTI line0 interrupt | true | 1 | 0
EXTI line2 interrupt | true | 1 | 0
FDCAN1 interrupt 0 | true | 1 | 0
TIM6 global interrupt, DAC1 and DAC3 channel underrun error interrupts | true | 2 | 0
TIM7 global interrupt | true | 0 | 0
PVD/PVM1/PVM2/PVM3/PVM4 interrupts through EXTI lines 16/38/39/40/41 | unused
Flash global interrupt | unused
RCC global interrupt | unused
ADC1 and ADC2 global interrupt | unused
FDCAN1 interrupt 1 | unused
SPI1 global interrupt | unused
USART1 global interrupt / USART1 wake-up interrupt through EXTI line 25 | unused
FPU global interrupt | unused
4.3.2. NVIC Code generation
Enabled interrupt Table | Select for init sequence ordering | Generate IRQ handler | Call HAL handler
Non maskable interrupt | false | true | false
Hard fault interrupt | false | true | false
Memory management fault | false | true | false
Prefetch fault, memory access fault | false | true | false
Undefined instruction or illegal state | false | true | false
System service call via SWI instruction | false | true | false
Debug monitor | false | true | false
Pendable request for system service | false | true | false
System tick timer | false | true | true

Enabled interrupt Table | Select for init sequence ordering | Generate IRQ handler | Call HAL handler
EXTI line0 interrupt | false | true | true
EXTI line2 interrupt | false | true | true
FDCAN1 interrupt 0 | false | true | true
TIM6 global interrupt, DAC1 and DAC3 channel underrun error interrupts | false | true | true
TIM7 global interrupt | false | true | true

* User modified value

## 5. System Views

5.1. Category view
5.1.1. Current

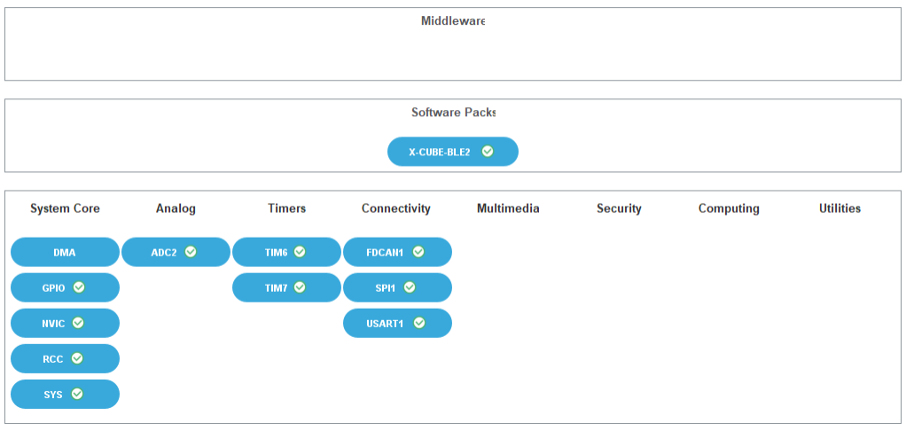
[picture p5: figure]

## 6. Software Pack Report

### 6.1. Software Pack selected

Vendor | Name | Version | Component
STMicroelectronic s | X-CUBE-BLE2 | 3.3.0 | Class : Wireless Group : BlueNRG-2 SubGroup : Controller Version : 3.3.0 Class : Wireless Group : BlueNRG-2 SubGroup : HCI_TL Variant : Basic Version : 3.3.0 Class : Wireless Group : BlueNRG-2 SubGroup : HCI_TL_INTERF ACE Variant : UserBoard Version : 3.3.0 Class : Wireless Group : BlueNRG-2 SubGroup : Utils Version : 3.3.0

## 7. Docs & Resources

Type | Link
BSDL files | https://www.st.com/resource/en/bsdl_model/stm32g4_bsdl.zip
IBIS models | https://www.st.com/resource/en/ibis_model/stm32g4_ibis.zip
System View Description | https://www.st.com/resource/en/svd/stm32g4_svd.zip
Presentations | https://www.st.com/resource/en/product_presentation/stm32-stm8_embedded_software_solutions.pdf
Presentations | https://www.st.com/resource/en/product_presentation/stm32_eval-tools_portfolio.pdf
Presentations | https://www.st.com/resource/en/product_presentation/stm32_stm8_functi onal-safety-packages.pdf
Presentations | https://www.st.com/resource/en/product_presentation/stm32-usb-c-pd-solutions-presentation.pdf
Presentations | https://www.st.com/resource/en/product_presentation/stm32-stm8_software_development_tools.pdf
Presentations | https://www.st.com/resource/en/product_presentation/microcontrollers-stm32-family-overview.pdf
Presentations | https://www.st.com/resource/en/product_presentation/microcontrollers-stm32g4-series-product-overview.pdf
Brochures | https://www.st.com/resource/en/brochure/products-and-solutions-for-plcs-and-smart-i-os.pdf
Flyers | https://www.st.com/resource/en/flyer/flstm32g4.pdf
Flyers | https://www.st.com/resource/en/flyer/flstm32nucleo.pdf
Flyers | https://www.st.com/resource/en/flyer/flstm32trust.pdf
Flyers | https://www.st.com/resource/en/flyer/fldpstpfc11120.pdf
Security Bulletin | https://www.st.com/resource/en/technical_note/tn1489-security-bulletin-tn1489stpsirt-physical-attacks-on-stm32-and-stm32cube-firmware-stmicroelectronics.pdf
Application Notes | https://www.st.com/resource/en/application_note/an1709-emc-design-guide-for-stm8-stm32-and-legacy-mcus-stmicroelectronics.pdf

Application Notes | https://www.st.com/resource/en/application_note/an2606-stm32-microcontroller-system-memory-boot-mode-stmicroelectronics.pdf
Application Notes | https://www.st.com/resource/en/application_note/an3126-audio-and-waveform-generation-using-the-dac-in-stm32-products-stmicroelectronics.pdf
Application Notes | https://www.st.com/resource/en/application_note/an3155-usart-protocol-used-in-the-stm32-bootloader-stmicroelectronics.pdf
Application Notes | https://www.st.com/resource/en/application_note/an3156-usb-dfu-protocol-used-in-the-stm32-bootloader-stmicroelectronics.pdf
Application Notes | https://www.st.com/resource/en/application_note/an4221-i2c-protocol-used-in-the-stm32-bootloader-stmicroelectronics.pdf
Application Notes | https://www.st.com/resource/en/application_note/an4232-getting-started-with-analog-comparators-for-stm32f3-series-and-stm32g4-series-devices-stmicroelectronics.pdf
Application Notes | https://www.st.com/resource/en/application_note/an4286-spi-protocol-used-in-the-stm32-bootloader-stmicroelectronics.pdf
Application Notes | https://www.st.com/resource/en/application_note/an4296-use-stm32f3stm32g4-ccm-sram-with-iar-embedded-workbench-keil-mdkarm-stmicroelectronics-stm32cubeide-and-other-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
Application Notes | https://www.st.com/resource/en/application_note/an4655-virtually-increasing-the-number-of-serial-communication-peripherals-in-stm32-applications-stmicroelectronics.p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
Application Notes | https://www.st.com/resource/en/application_note/an4750-handling-of-soft-errors-in-stm32-applications-stmicroelectronics.pdf
Application Notes | https://www.st.com/resource/en/application_note/an4776-generalpurpose-timer-cookbook-for-stm32-microcontrollers-stmicroelectronics.pdf
Application Notes | https://www.st.com/resource/en/application_note/an4803-highspeed-si-simulations-using-ibis-and-boardlevel-simulations-using-hyperlynx-si-on-stm32-mcus-and-mpus-stmic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
Application Notes | https://www.st.com/resource/en/application_note/an4989-stm32-microcontroller-debug-toolbox-stmicroelectronics.pdf
Application Notes | https://www.st.com/resource/en/application_note/an5027-interfacing-pdm-

| digital-microphones-using-stm32-mcus-and-mpus-stmicroelectronics.pdf
Application Notes | https://www.st.com/resource/en/application_note/an5093-getting-started-with-stm32g4-series--hardware-development-boards-stmicroelectronics.pdf
Application Notes | https://www.st.com/resource/en/application_note/an5306-operational-amplifier-opamp-usage-in-stm32g4-series-stmicroelectronics.pdf
Application Notes | https://www.st.com/resource/en/application_note/an5310-guideline-for-using-analog-features-of-stm32g4-series-versus-stm32f3-series-devices-stmicroelectronics.pdf
Application Notes | https://www.st.com/resource/en/application_note/an5315-stm32cube-firmware-examples-for-stm32g4-series-stmicroelectronics.pdf
Application Notes | https://www.st.com/resource/en/application_note/an5346-stm32g4-adc-use-tips-and-recommendations-stmicroelectronics.pdf
Application Notes | https://www.st.com/resource/en/application_note/an5094-migrating-between-stm32f334303-lines-and-stm32g431xxg474xxg491xx-microcontrollers-stmicroelectronics.pdf
Application Notes | https://www.st.com/resource/en/application_note/an5738-stm32g4-series-lifetime-estimates-stmicroelectronics.pdf
Application Notes | https://www.st.com/resource/en/application_note/an4899-stm32-microcontroller-gpio-hardware-settings-and-lowpower-consumption-stmicroelectronics.pdf
Application Notes | https://www.st.com/resource/en/application_note/an5612-esd-protection-of-stm32-mcus-and-mpus-stmicroelectronics.pdf
Application Notes | https://www.st.com/resource/en/application_note/an4991-how-to-wake-up-an-stm32-microcontroller-from-lowpower-mode-with-the-usart-or-the-lpuart-stmicroelectronics.pdf
Application Notes | https://www.st.com/resource/en/application_note/an4838-introduction-to-memory-protection-unit-management-on-stm32-mcus-stmicroelectronics.pdf
Application Notes | https://www.st.com/resource/en/application_note/an5325-how-to-use-the-cordic-to-perform-mathematical-functions-on-stm32-mcus-stmicroelectronics.pdf
Application Notes | https://www.st.com/resource/en/application_note/an5225-introduction-to-

| usb-typec-power-delivery-for-stm32-mcus-and-mpus-stmicroelectronics.pdf
Application Notes | https://www.st.com/resource/en/application_note/an4894-how-to-use-eeprom-emulation-on-stm32-mcus-stmicroelectronics.pdf
Application Notes | https://www.st.com/resource/en/application_note/an5537-how-to-use-adc-oversampling-techniques-to-improve-signaltonoise-ratio-on-stm32-mcus-stmicroelectronics.pdf
Application Notes | https://www.st.com/resource/en/application_note/an5036-guidelines-for-thermal-management-on-stm32-applications-stmicroelectronics.pdf
Application Notes | https://www.st.com/resource/en/application_note/an5405-how-to-use-fdcan-bootloader-protocol-on-stm32-mcus-stmicroelectronics.pdf
Application Notes | https://www.st.com/resource/en/application_note/an5978-introduction-to-mb1971-llc-hat-12-v-to-75-v1-a-for-f334-g474-nucleo-board-stmicroelectronics.pdf
Application Notes | https://www.st.com/resource/en/application_note/an5690-how-to-use-vrefbuf-peripheral-on-stm32-mcus-and-mpus-stmicroelectronics.pdf
Application Notes | https://www.st.com/resource/en/application_note/an4230-introduction-to-random-number-generation-validation-using-the-nist-statistical-test-suite-for-stm32-mcus-and-m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
Application Notes | https://www.st.com/resource/en/application_note/an2548-introduction-to-dma-controller-for-stm32-mcus-stmicroelectronics.pdf
Application Notes | https://www.st.com/resource/en/application_note/an4013-introduction-to-timers-for-stm32-mcus-stmicroelectronics.pdf
Application Notes | https://www.st.com/resource/en/application_note/an4277-how-to-use-pwm-shutdown-for-motor-control-and-digital-power-conversion-on-stm32-mcus-stmicroelectronics.pdf
Application Notes | https://www.st.com/resource/en/application_note/an4635-how-to-optimize-lpuart-power-consumption-on-stm32-mcus-stmicroelectronics.pdf
Application Notes | https://www.st.com/resource/en/application_note/an4759-introduction-to-using-the-hardware-realtime-clock-rtc-and-the-tamper-management-unit-tamp-with-stm32-mcus-stmi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
Application Notes | https://www.st.com/resource/en/application_note/an4908-getting-started-

| with-usart-automatic-baud-rater-detection-for-stm32-mcus-stmicroelectronics.pdf
Application Notes | https://www.st.com/resource/en/application_note/an5156-introduction-to-security-for-stm32-mcus-stmicroelectronics.pdf
Application Notes | https://www.st.com/resource/en/application_note/an5224-introduction-to-dmamux-for-stm32-mcus-stmicroelectronics.pdf
Application Notes | https://www.st.com/resource/en/application_note/an5543-guidelines-for-enhanced-spi-communication-on-stm32-mcus-and-mpus-stmicroelectronics.pdf
Application Notes | https://www.st.com/resource/en/application_note/an5348-introduction-to-fdcan-peripherals-for-stm32-mcus-stmicroelectronics.pdf
Application Notes | https://www.st.com/resource/en/application_note/cd00211314-how-to-optimize-the-adc-accuracy-in-the-stm32-mcus-stmicroelectronics.pdf
Application Notes | https://www.st.com/resource/en/application_note/an2639-soldering-recommendations-and-package-information-for-leadfree-ecopack2-mcus-and-mpus-stmicroelectronics.pdf
Application Notes | https://www.st.com/resource/en/application_note/an4566-how-to-extend-the-dac-performance-on-stm32-mcus-stmicroelectronics.pdf
Application Notes for related Tools & Software | https://www.st.com/resource/en/application_note/an4435-guidelines-for-obtaining-ulcsaiec-607301603351-class-b-certification-in-any-stm32-application-stmicroelectroni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
Application Notes for related Tools & Software | https://www.st.com/resource/en/application_note/an4657-stm32-inapplication-programming-iap-using-the-usart-stmicroelectronics.pdf
Application Notes for related Tools & Software | https://www.st.com/resource/en/application_note/an4841-digital-signal-processing-for-stm32-microcontrollers-using-cmsis-stmicroelectronics.pdf
Application Notes for related Tools & Software | https://www.st.com/resource/en/application_note/an5056-integration-guide-for-the-xcubesbsfu-stm32cube-expansion-package-stmicroelectronics.pdf
Application Notes for related Tools & Software | https://www.st.com/resource/en/application_note/an5305-digital-filter-implementation-with-the-fmac-using-stm32cubeg4-mcu-package-stmicroelectronics.pdf

Application Notes for related Tools & Software | https://www.st.com/resource/en/application_note/an5315-stm32cube-firmware-examples-for-stm32g4-series-stmicroelectronics.pdf
Application Notes for related Tools & Software | https://www.st.com/resource/en/application_note/an5345-highbrightness-rgb-led-control-using-the-bg474edpow1-discovery-kit-stmicroelectronics.pdf
Application Notes for related Tools & Software | https://www.st.com/resource/en/application_note/an5360-getting-started-with-projects-based-on-the-stm32mp1-series-in-stm32cubeide-stmicroelectronics.pdf
Application Notes for related Tools & Software | https://www.st.com/resource/en/application_note/an5361-getting-started-with-projects-based-on-dualcore-stm32h7-microcontrollers-in-stm32cubeide-stmicroelectronics.pd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
Application Notes for related Tools & Software | https://www.st.com/resource/en/application_note/an5394-getting-started-with-projects-based-on-the-stm32l5-series-in-stm32cubeide-stmicroelectronics.pdf
Application Notes for related Tools & Software | https://www.st.com/resource/en/application_note/an5418-how-to-build-a-simple-usbpd-sink-application-with-stm32cubemx-stmicroelectronics.pdf
Application Notes for related Tools & Software | https://www.st.com/resource/en/application_note/an5426-migrating-graphics-middleware-projects-from-stm32cubemx-540-to-stm32cubemx-550-stmicroelectronics.pdf
Application Notes for related Tools & Software | https://www.st.com/resource/en/application_note/an5464-position-control-of-a-threephase-permanent-magnet-motor-using-xcubemcsdk-or-xcubemcsdkful-stmicroelectronics.p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
Application Notes for related Tools & Software | https://www.st.com/resource/en/application_note/an5564-getting-started-with-projects-based-on-dualcore-stm32wl-microcontrollers-in-stm32cubeide-stmicroelectronics.pd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
Application Notes for related Tools & Software | https://www.st.com/resource/en/application_note/an5698-adapting-the-xcubestl-functional-safety-package-for-stm32-iec-61508-compliant-to-other-safety-standards-stmicr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
Application Notes for related Tools & Software | https://www.st.com/resource/en/application_note/an5731-stm32cubemx-and-stm32cubeide-threadsafe-solution-stmicroelectronics.pdf
Application Notes | https://www.st.com/resource/en/application_note/an5785-boost-voltage-

for related Tools & Software | mode-on-bg474edpow1-discovery-kit-stmicroelectronics.pdf
Application Notes for related Tools & Software | https://www.st.com/resource/en/application_note/an5788-stm32-digital-power-pid-and-iir-filters-for-smps-control-design-and-comparison-on-bg414edpow1-discovery-kit-st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
Application Notes for related Tools & Software | https://www.st.com/resource/en/application_note/an4502-stm32-smbuspmbus-expansion-package-for-stm32cube-stmicroelectronics.pdf
Application Notes for related Tools & Software | https://www.st.com/resource/en/application_note/an5952-how-to-use-cmake-in-stm32cubeide-stmicroelectronics.pdf
Application Notes for related Tools & Software | https://www.st.com/resource/en/application_note/an4635-how-to-optimize-lpuart-power-consumption-on-stm32-mcus-stmicroelectronics.pdf
Application Notes for related Tools & Software | https://www.st.com/resource/en/application_note/an5054-how-to-perform-secure-programming-using-stm32cubeprogrammer-stmicroelectronics.pdf
Application Notes for related Tools & Software | https://www.st.com/resource/en/application_note/an5496-guidelines-for-the-buck-voltage-mode-on-the-bg474edpow1-discovery-kit-stmicroelectronics.pdf
Application Notes for related Tools & Software | https://www.st.com/resource/en/application_note/an5497-introduction-to-the-buck-current-mode-with-the-bg474edpow1-discovery-kit-stmicroelectronics.pdf
Application Notes for related Tools & Software | https://www.st.com/resource/en/application_note/an6179-how-to-integrate-the-stl-firmware-into-a-time-critical-user-application-stmicroelectronics.pdf
Application Notes for related Tools & Software | https://www.st.com/resource/en/application_note/an6127-getting-started-with-stm32h7rx7sx-mcus-in-stm32cubeide-stmicroelectronics.pdf
Errata Sheets | https://www.st.com/resource/en/errata_sheet/es0431-stm32g431xx441xx-device-errata-stmicroelectronics.pdf
Datasheet | https://www.st.com/resource/en/datasheet/dm00507199.pdf
Programming Manuals | https://www.st.com/resource/en/programming_manual/pm0214-stm32-cortexm4-mcus-and-mpus-programming-manual-stmicroelectronics.pdf

Reference Manuals | https://www.st.com/resource/en/reference_manual/rm0440-stm32g4-series-advanced-armbased-32bit-mcus-stmicroelectronics.pdf
Technical Notes & Articles | https://www.st.com/resource/en/technical_note/tn1163-description-of-wlcsp-for-microcontrollers-and-recommendations-for-its-use-stmicroelectronics.pdf
Technical Notes & Articles | https://www.st.com/resource/en/technical_note/tn1204-tape-and-reel-shipping-media-for-stm32-microcontrollers-in-bga-packages-stmicroelectronics.pdf
Technical Notes & Articles | https://www.st.com/resource/en/technical_note/tn1205-tape-and-reel-shipping-media-for-stm8-and-stm32-microcontrollers-in-fpn-packages-stmicroelectronics.pdf
Technical Notes & Articles | https://www.st.com/resource/en/technical_note/tn1206-tape-and-reel-shipping-media-for-stm8-and-stm32-microcontrollers-in-qfp-packages-stmicroelectronics.pdf
Technical Notes & Articles | https://www.st.com/resource/en/technical_note/tn1207-tape-and-reel-shipping-media-for-stm8-and-stm32-microcontrollers-in-so-packages-stmicroelectronics.pdf
Technical Notes & Articles | https://www.st.com/resource/en/technical_note/tn1208-tape-and-reel-shipping-media-for-stm8-and-stm32-microcontrollers-in-tssop-and-ssop-packages-stmicroelectronics.p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
Technical Notes & Articles | https://www.st.com/resource/en/technical_note/tn1433-reference-device-marking-schematics-for-stm32-microcontrollers-and-microprocessors-stmicroelectronics.pdf
User Manuals | https://www.st.com/resource/en/user_manual/um3167-stm32g4-series-ulcsaiec-607301603351-selftest-library-user-guide-stmicroelectronics.pdf

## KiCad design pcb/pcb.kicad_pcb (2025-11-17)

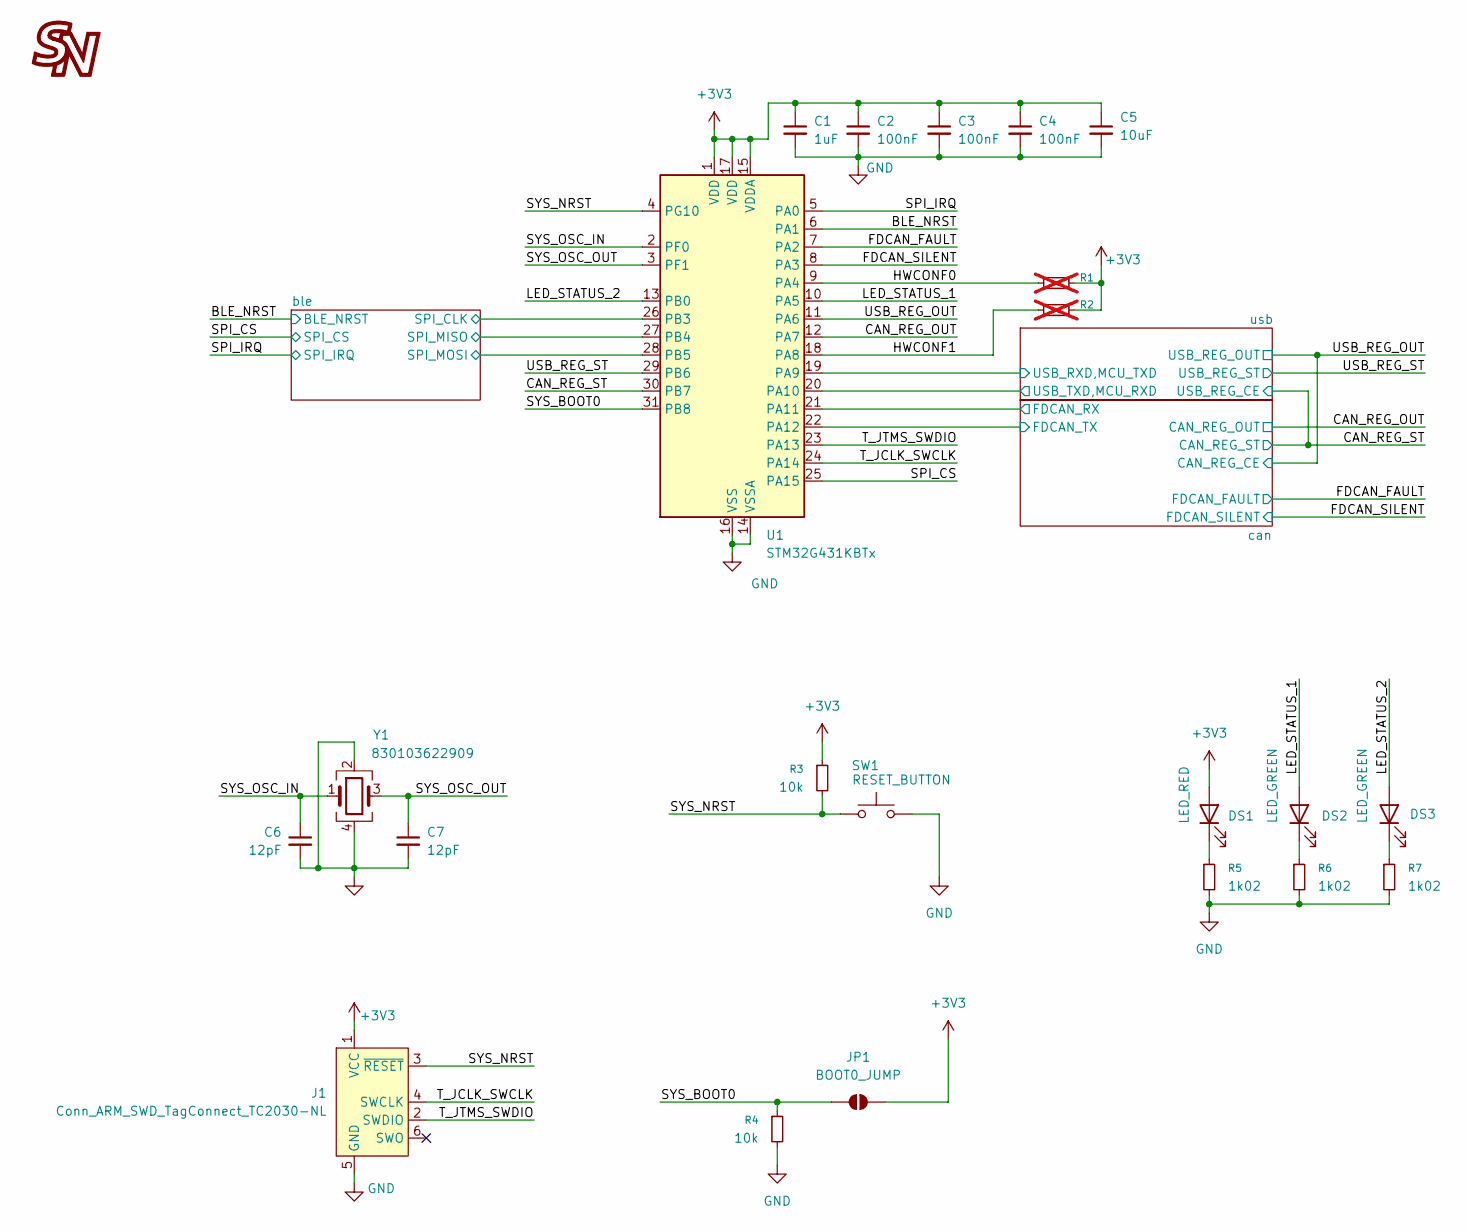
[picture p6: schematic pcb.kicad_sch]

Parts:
C1: 1uF; C_0603_1608Metric; LCSC C559769
C2, C3, C4: 100nF; C_0603_1608Metric; LCSC C14663
C5: 10uF; C_0603_1608Metric; LCSC C92487
C6, C7: 12pF; C_0603_1608Metric; LCSC C107034
DS1: LED_RED; LED_0603_1608Metric; LCSC C965799
DS2, DS3: LED_GREEN; LED_0603_1608Metric; LCSC C965804
G1: LOGO; logo
J1: Conn_ARM_SWD_TagConnect_TC2030-NL; Tag-Connect_TC2030-IDC-NL_2x03_P1.27mm_Vertical
JP1: BOOT0_JUMP; SolderJumper-2_P1.3mm_Open_Pad1.0x1.5mm
R1, R2: 0R; R_0603_1608Metric; LCSC C21189; not fitted
R3, R4: 10k; R_0603_1608Metric; LCSC C25804
R5, R6, R7: 1k02; R_0603_1608Metric; LCSC C22831
SW1: RESET_BUTTON; TS-1187A-ABAB; LCSC C318884
U1: STM32G431KBTx; LQFP-32_7x7mm_P0.8mm; LCSC C5270317
Y1: 830103622909; Crystal_SMD_3225-4Pin_3.2x2.5mm; LCSC C9009

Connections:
+3V3: C1.1, C2.1, C3.1, C4.1, C5.1, DS1.2 (A), J1.1 (VCC), JP1.2 (B), R1.2, R2.2, R3.1, U1.1 (VDD), U1.15 (VDDA), U1.17 (VDD); also elsewhere on the board
/BLE_NRST: U1.6 (PA1); also elsewhere on the board
/CAN_REG_OUT: U1.12 (PA7); also elsewhere on the board
/CAN_REG_ST: U1.30 (PB7); also elsewhere on the board
/FDCAN_FAULT: U1.7 (PA2); also elsewhere on the board
/FDCAN_SILENT: U1.8 (PA3); also elsewhere on the board
/HWCONF0: R1.1, U1.9 (PA4)
/HWCONF1: R2.1, U1.18 (PA8)
/LED_STATUS_1: DS2.2 (A), U1.10 (PA5)
/LED_STATUS_2: DS3.2 (A), U1.13 (PB0)
/SPI_CS: U1.25 (PA15); also elsewhere on the board
/SPI_IRQ: U1.5 (PA0); also elsewhere on the board
/SYS_BOOT0: JP1.1 (A), R4.1, U1.31 (PB8)
/SYS_NRST: J1.3 (~RESET), R3.2, SW1.1, U1.4 (PG10)
/SYS_OSC_IN: C6.1, U1.2 (PF0), Y1.1
/SYS_OSC_OUT: C7.1, U1.3 (PF1), Y1.3
/T_JCLK_SWCLK: J1.4 (SWCLK), U1.24 (PA14)
/T_JTMS_SWDIO: J1.2 (SWDIO), U1.23 (PA13)
/USB_REG_OUT: U1.11 (PA6); also elsewhere on the board
/USB_REG_ST: U1.29 (PB6); also elsewhere on the board
/ble/SPI_CLK: U1.26 (PB3); also elsewhere on the board
/ble/SPI_MISO: U1.27 (PB4); also elsewhere on the board
/ble/SPI_MOSI: U1.28 (PB5); also elsewhere on the board
/can/FDCAN_RX: U1.21 (PA11); also elsewhere on the board
/can/FDCAN_TX: U1.22 (PA12); also elsewhere on the board
/usb/USB_RXD,MCU_TXD: U1.19 (PA9); also elsewhere on the board
/usb/USB_TXD,MCU_RXD: U1.20 (PA10); also elsewhere on the board
GND: C1.2, C2.2, C3.2, C4.2, C5.2, C6.2, C7.2, J1.5 (GND), R4.2, R5.2, R6.2, R7.2, SW1.2, U1.14 (VSSA), U1.16 (VSS), U1.32 (VSS), Y1.2, Y1.4; also elsewhere on the board
unnamed: DS1.1 (K), R5.1
unnamed: DS2.1 (K), R6.1
unnamed: DS3.1 (K), R7.1

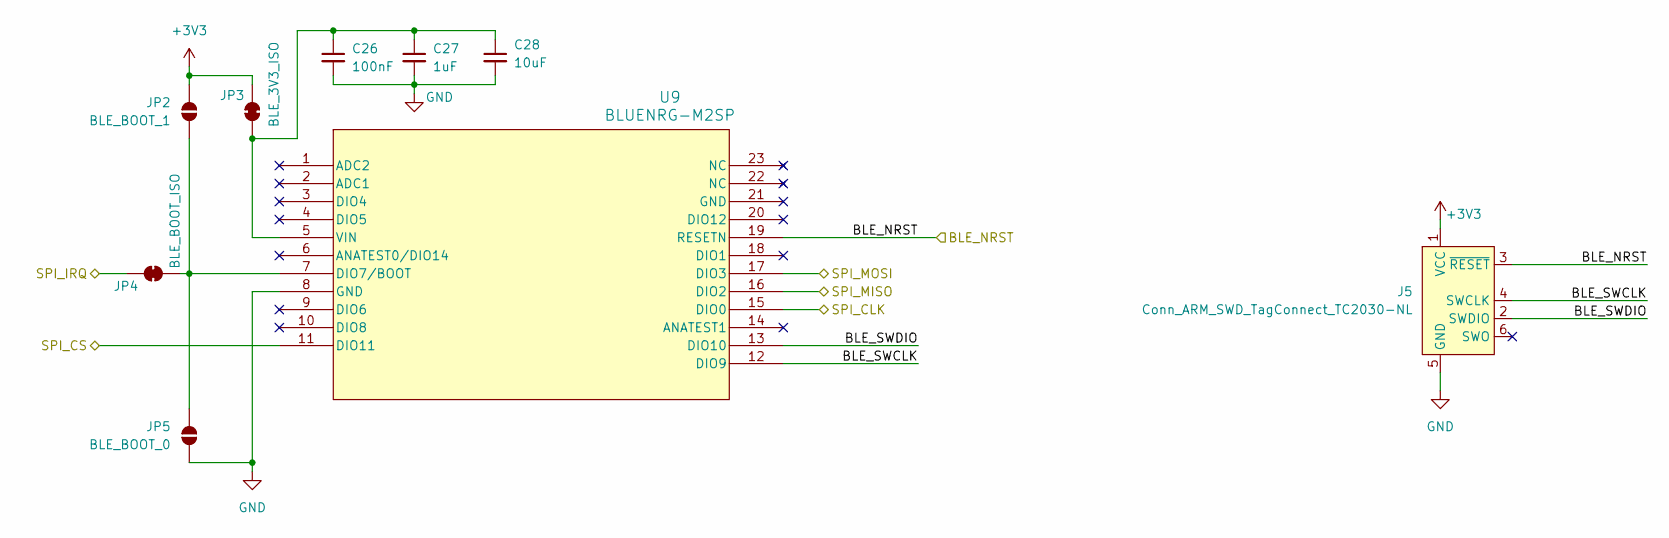
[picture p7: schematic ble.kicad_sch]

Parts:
C26: 100nF; C_0603_1608Metric; LCSC C14663
C27: 1uF; C_0603_1608Metric; LCSC C559769
C28: 10uF; C_0603_1608Metric; LCSC C92487
J5: Conn_ARM_SWD_TagConnect_TC2030-NL; Tag-Connect_TC2030-IDC-NL_2x03_P1.27mm_Vertical
JP2: BLE_BOOT_1; SolderJumper-2_P1.3mm_Open_Pad1.0x1.5mm
JP3: BLE_3V3_ISO; SolderJumper-2_P1.3mm_Bridged_Pad1.0x1.5mm
JP4: BLE_BOOT_ISO; SolderJumper-2_P1.3mm_Bridged_Pad1.0x1.5mm
JP5: BLE_BOOT_0; SolderJumper-2_P1.3mm_Open_Pad1.0x1.5mm
U9: BLUENRG-M2SP; BLUENRG-2M_STM; LCSC C1850403

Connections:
+3V3: J5.1 (VCC), JP2.2 (B), JP3.1 (A); also elsewhere on the board
/BLE_NRST: J5.3 (~RESET), U9.19 (RESETN); also elsewhere on the board
/SPI_CS: U9.11 (DIO11); also elsewhere on the board
/SPI_IRQ: JP4.1 (A); also elsewhere on the board
/ble/BLE_SWCLK: J5.4 (SWCLK), U9.12 (DIO9)
/ble/BLE_SWDIO: J5.2 (SWDIO), U9.13 (DIO10)
/ble/SPI_CLK: U9.15 (DIO0); also elsewhere on the board
/ble/SPI_MISO: U9.16 (DIO2); also elsewhere on the board
/ble/SPI_MOSI: U9.17 (DIO3); also elsewhere on the board
GND: C26.2, C27.2, C28.2, J5.5 (GND), JP5.1 (A), U9.8 (GND); also elsewhere on the board
unnamed: JP2.1 (A), JP4.2 (B), JP5.2 (B), U9.7 (DIO7/BOOT)
unnamed: C26.1, C27.1, C28.1, JP3.2 (B), U9.5 (VIN)

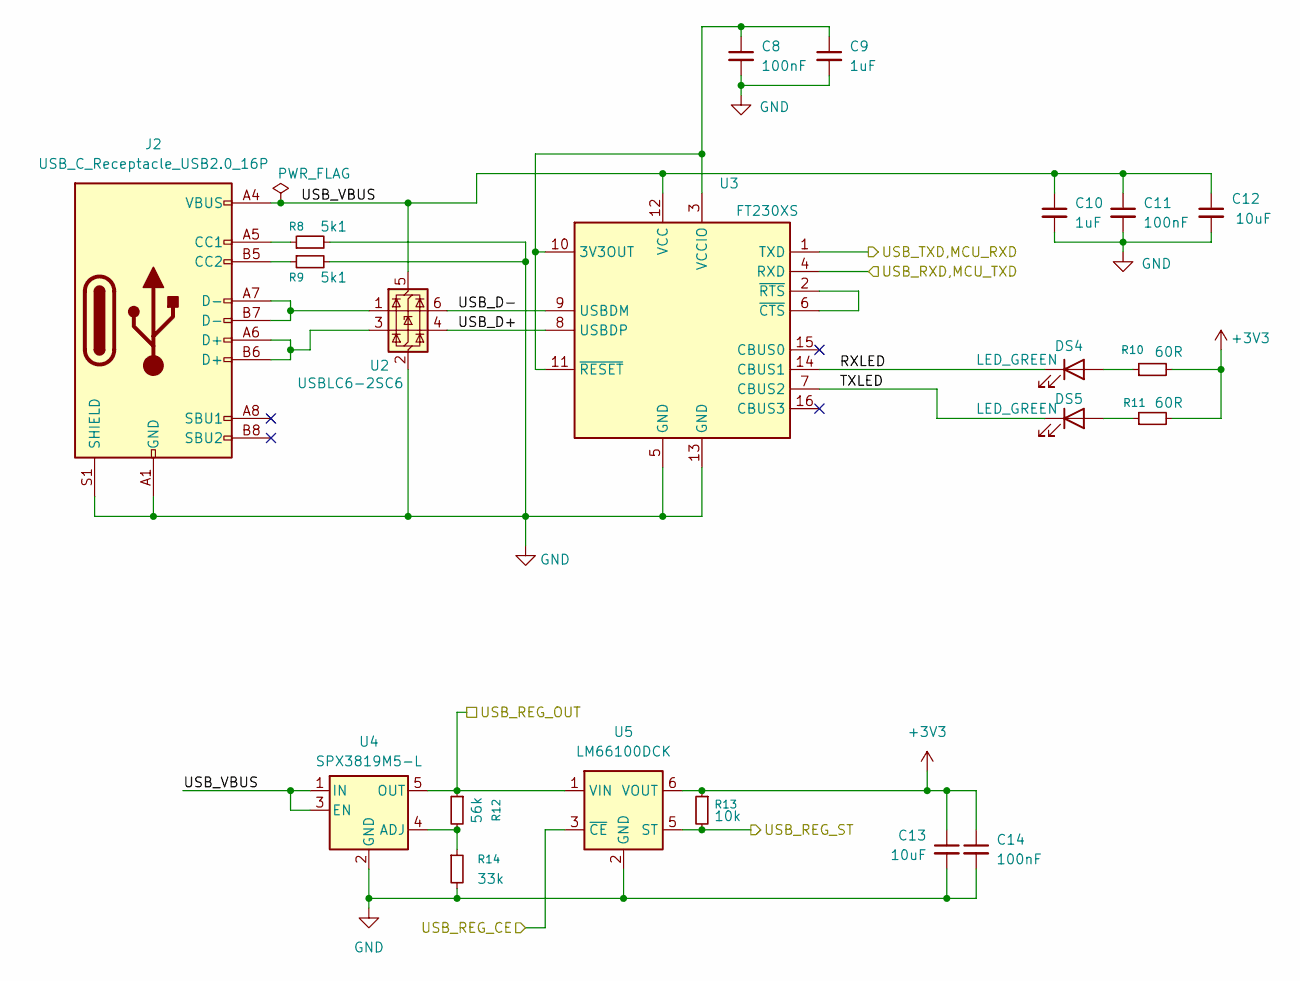
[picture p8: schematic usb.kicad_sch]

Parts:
C8, C11, C14: 100nF; C_0603_1608Metric; LCSC C14663
C9, C10: 1uF; C_0603_1608Metric; LCSC C559769
C12, C13: 10uF; C_0603_1608Metric; LCSC C92487
DS4, DS5: LED_GREEN; LED_0603_1608Metric; LCSC C965804
J2: USB_C_Receptacle_USB2.0_16P; USB_C_Receptacle_G-Switch_GT-USB-7010ASV; LCSC C2988369
R8, R9: 5k1; R_0603_1608Metric; LCSC C23186
R10, R11: 60R; R_0603_1608Metric; LCSC C166918
R12: 56k; R_0603_1608Metric; LCSC C23206
R13: 10k; R_0603_1608Metric; LCSC C25804
R14: 33k; R_0603_1608Metric; LCSC C4216
U2: USBLC6-2SC6; SOT-23-6; LCSC C7519
U3: FT230XS; SSOP-16_3.9x4.9mm_P0.635mm; LCSC C69082
U4: SPX3819M5-L; SOT-23-5; LCSC C9056
U5: LM66100DCK; SOT-363_SC-70-6; LCSC C2869734

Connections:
+3V3: C13.1, C14.1, R10.2, R11.2, R13.1, U5.6 (VOUT); also elsewhere on the board
/CAN_REG_ST: U5.3 (~CE); also elsewhere on the board
/USB_REG_OUT: R12.1, U4.5 (OUT), U5.1 (VIN); also elsewhere on the board
/USB_REG_ST: R13.2, U5.5 (ST); also elsewhere on the board
/usb/RXLED: DS4.1 (K), U3.14 (CBUS1)
/usb/TXLED: DS5.1 (K), U3.7 (CBUS2)
/usb/USB_D+: U2.4 (I/O2), U3.8 (USBDP)
/usb/USB_D-: U2.6 (I/O1), U3.9 (USBDM)
/usb/USB_RXD,MCU_TXD: U3.4 (RXD); also elsewhere on the board
/usb/USB_TXD,MCU_RXD: U3.1 (TXD); also elsewhere on the board
/usb/USB_VBUS: C10.1, C11.1, C12.1, J2.A4 (VBUS), J2.A9 (VBUS), J2.B4 (VBUS), J2.B9 (VBUS), U2.5 (VBUS), U3.12 (VCC), U4.1 (IN), U4.3 (EN)
GND: C8.2, C9.2, C10.2, C11.2, C12.2, C13.2, C14.2, J2.A1 (GND), J2.A12 (GND), J2.B1 (GND), J2.B12 (GND), J2.S1 (SHIELD), R8.2, R9.2, R14.2, U2.2 (GND), U3.5 (GND), U3.13 (GND), U4.2 (GND), U5.2 (GND); also elsewhere on the board
unnamed: DS4.2 (A), R10.1
unnamed: DS5.2 (A), R11.1
unnamed: J2.A5 (CC1), R8.1
unnamed: J2.B5 (CC2), R9.1
unnamed: J2.A6 (D+), J2.B6 (D+), U2.3 (I/O2)
unnamed: J2.A7 (D-), J2.B7 (D-), U2.1 (I/O1)
unnamed: C8.1, C9.1, U3.3 (VCCIO), U3.10 (3V3OUT), U3.11 (~RESET)
unnamed: U3.2 (~RTS), U3.6 (~CTS)
unnamed: R12.2, R14.1, U4.4 (ADJ)

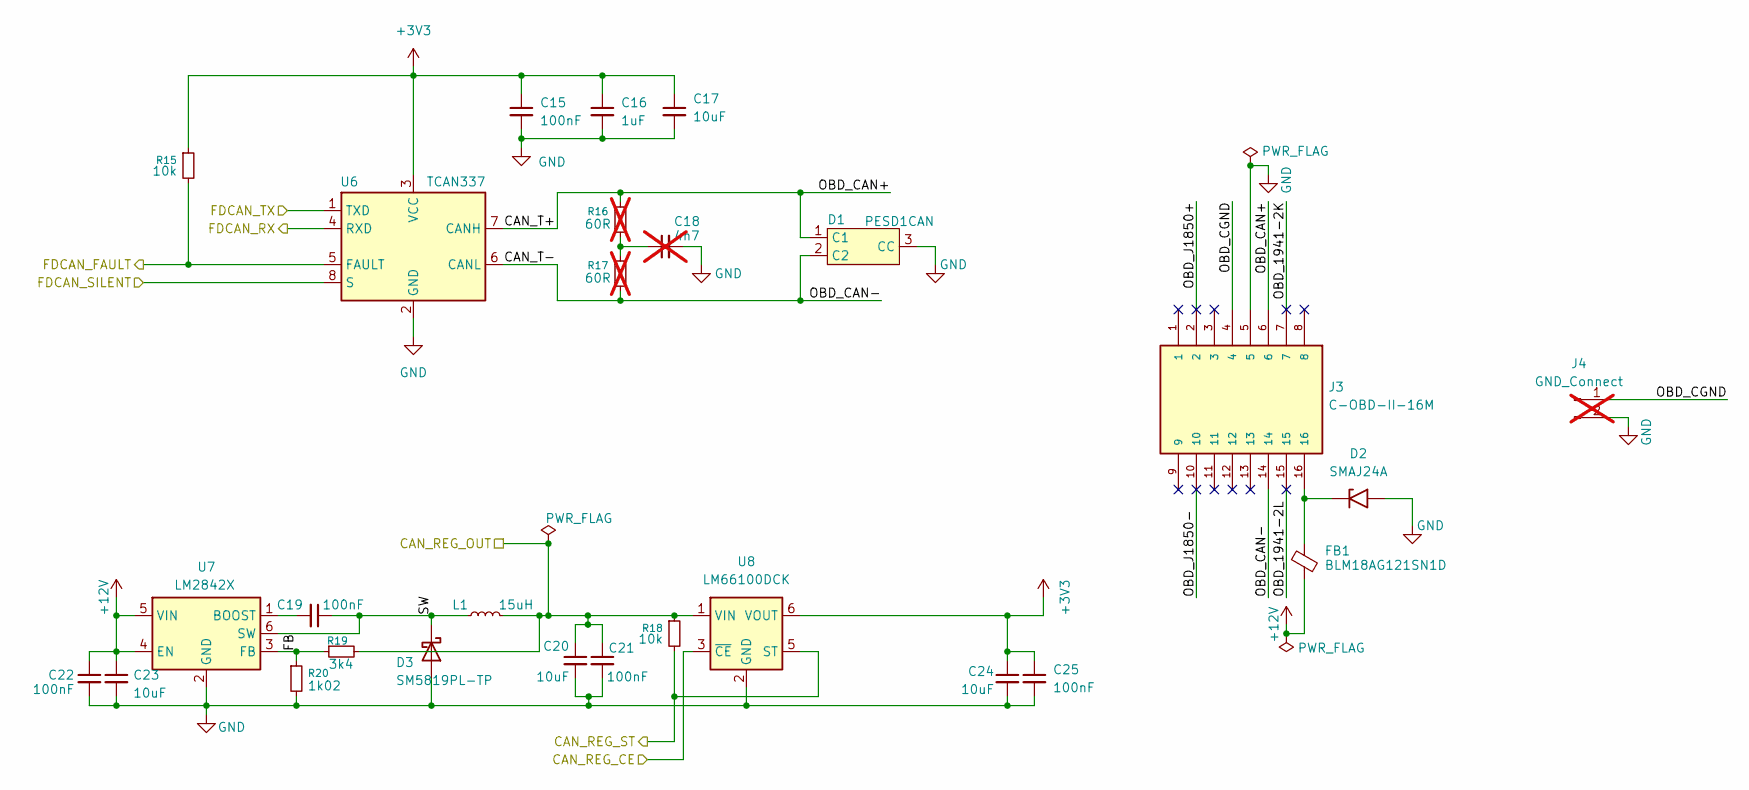
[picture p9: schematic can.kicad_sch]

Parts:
C15, C19, C21, C22, C25: 100nF; C_0603_1608Metric; LCSC C14663
C16: 1uF; C_0603_1608Metric; LCSC C559769
C17, C20, C23, C24: 10uF; C_0603_1608Metric; LCSC C92487
C18: 4n7; C_0603_1608Metric; LCSC C106218; not fitted
D1: PESD1CAN; TSOT-23; LCSC C15771
D2: SMAJ24A; D_SMA; LCSC C113962
D3: SM5819PL-TP; D_SOD-123F; LCSC C669023
FB1: BLM18AG121SN1D; L_0603_1608Metric; LCSC C76892
J3: C-OBD-II-16M; COMTECH_C-OBD-II-16M
J4: GND_Connect; PinHeader_1x02_P2.54mm_Vertical; not fitted
L1: 15uH; L_Wurth_WE-LQSH-3012; LCSC C668450
R15, R18: 10k; R_0603_1608Metric; LCSC C25804
R16, R17: 60R; R_0603_1608Metric; LCSC C166918; not fitted
R19: 3k4; R_0603_1608Metric; LCSC C22997
R20: 1k02; R_0603_1608Metric; LCSC C22831
U6: TCAN337; SOIC-8_3.9x4.9mm_P1.27mm; LCSC C2860648
U7: LM2842X; TSOT-23-6; LCSC C2865947
U8: LM66100DCK; SOT-363_SC-70-6; LCSC C2869734

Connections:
+3V3: C15.1, C16.1, C17.1, C24.1, C25.1, R15.1, U6.3 (VCC), U8.6 (VOUT); also elsewhere on the board
+12V: C22.1, C23.1, FB1.2, U7.4 (EN), U7.5 (VIN)
/CAN_REG_OUT: C20.1, C21.1, L1.2, R18.1, R19.2, U8.1 (VIN); also elsewhere on the board
/CAN_REG_ST: R18.2, U8.5 (ST); also elsewhere on the board
/FDCAN_FAULT: R15.2, U6.5 (FAULT); also elsewhere on the board
/FDCAN_SILENT: U6.8 (S); also elsewhere on the board
/USB_REG_OUT: U8.3 (~CE); also elsewhere on the board
/can/CAN_T+: D1.1 (C1), J3.6, R16.1, U6.7 (CANH)
/can/CAN_T-: D1.2 (C2), J3.14, R17.1, U6.6 (CANL)
/can/FB: R19.1, R20.1, U7.3 (FB)
/can/FDCAN_RX: U6.4 (RXD); also elsewhere on the board
/can/FDCAN_TX: U6.1 (TXD); also elsewhere on the board
/can/OBD_1941-2K: J3.7
/can/OBD_1941-2L: J3.15
/can/OBD_CGND: J3.4, J4.1
/can/OBD_J1850+: J3.2
/can/OBD_J1850-: J3.10
/can/SW: C19.1, D3.1 (K), L1.1, U7.6 (SW)
GND: C15.2, C16.2, C17.2, C18.2, C20.2, C21.2, C22.2, C23.2, C24.2, C25.2, D1.3 (CC), D2.2 (A2), D3.2 (A), J3.5, J4.2, R20.2, U6.2 (GND), U7.2 (GND), U8.2 (GND); also elsewhere on the board
unnamed: C18.1, R16.2, R17.2
unnamed: D2.1 (A1), FB1.1, J3.16
unnamed: C19.2, U7.1 (BOOST)

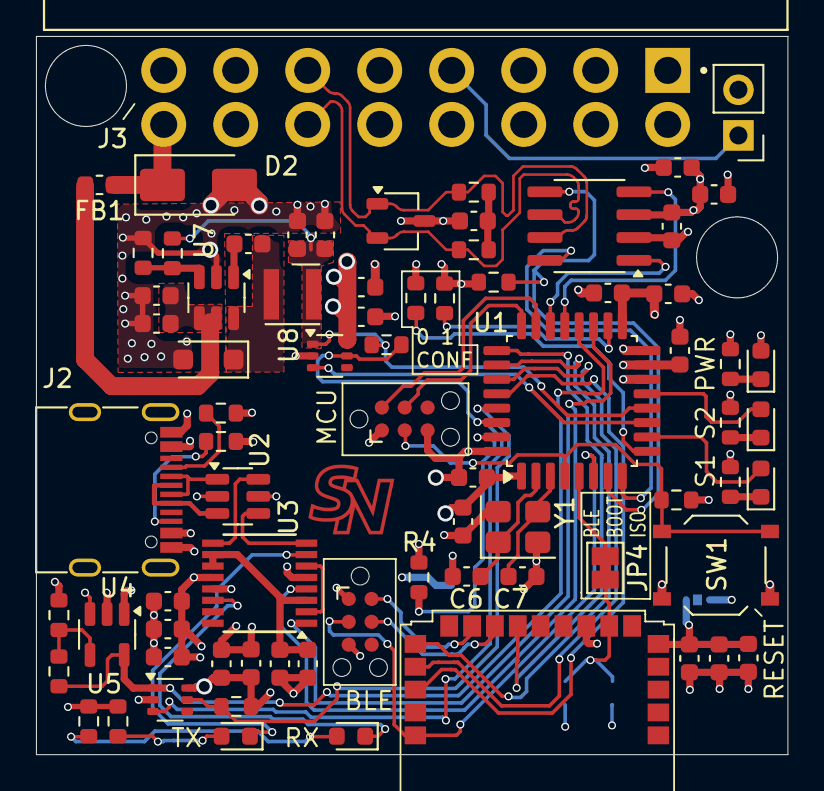
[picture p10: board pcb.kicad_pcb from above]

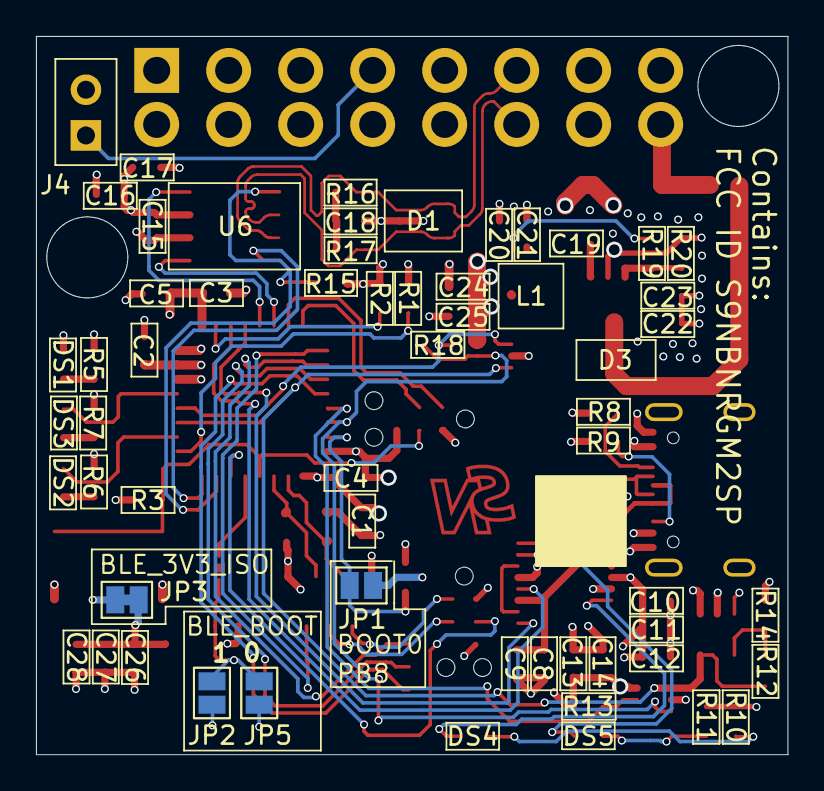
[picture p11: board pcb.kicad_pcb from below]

Board: 4 copper layers, 41.8 x 39.9 mm, 80 parts (4 on the bottom side), 58 nets.

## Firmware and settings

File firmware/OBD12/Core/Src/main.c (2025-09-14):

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
/* Includes ------------------------------------------------------------------*/
#include "main.h"

/* USER CODE BEGIN Includes */
#include <stdio.h>

#include "_Debug.h"
#include "BLE/App.h"
#include "CAN/CAN.h"
#include "CAN/OBD.h"
#include "UART/Uart.h"
/* USER CODE END Includes */

ADC_HandleTypeDef hadc2;

FDCAN_HandleTypeDef hfdcan1;

TIM_HandleTypeDef htim6;
TIM_HandleTypeDef htim7;

UART_HandleTypeDef huart1;

void SystemClock_Config(void);
static void MX_GPIO_Init(void);
static void MX_ADC2_Init(void);
static void MX_USART1_UART_Init(void);
static void MX_FDCAN1_Init(void);
static void MX_TIM6_Init(void);
static void MX_TIM7_Init(void);
/* USER CODE BEGIN 0 */

#define UART_RX_BUFFER_SIZE 1
uint8_t UartRxBuffer[UART_RX_BUFFER_SIZE];
size_t UartRxDataLength = 0;

int __io_putchar(int ch) {
	HAL_UART_Transmit(&huart1, (uint8_t*) &ch, 1, HAL_MAX_DELAY);
	return ch;
}

void HAL_UART_RxCpltCallback(UART_HandleTypeDef *huart) {
	UART_USB_RX(UartRxBuffer, UART_RX_BUFFER_SIZE);
	HAL_UART_Receive_IT(&huart1, UartRxBuffer, UART_RX_BUFFER_SIZE);
}

void HAL_FDCAN_RxFifo0Callback(FDCAN_HandleTypeDef *hfdcan, uint32_t RxFifo0ITs) {
	CAN_Rx(hfdcan, RxFifo0ITs);
}

/* USER CODE END 0 */

/**
 * @brief  The application entry point.
 * @retval int
 */
int main(void) {

	/* MCU Configuration--------------------------------------------------------*/

	/* Reset of all peripherals, Initializes the Flash interface and the Systick. */
	HAL_Init();

	/* Configure the system clock */
	SystemClock_Config();

	/* Initialize all configured peripherals */
	MX_GPIO_Init();
	MX_ADC2_Init();
	MX_USART1_UART_Init();
	MX_FDCAN1_Init();
	MX_TIM6_Init();
	MX_TIM7_Init();
	/* USER CODE BEGIN 2 */
	MX_BlueNRG_2_Init();
	CAN_Config(&hfdcan1);

	MX_USART1_UART_Init();
	HAL_UART_Receive_IT(&huart1, UartRxBuffer, UART_RX_BUFFER_SIZE);

	/* USER CODE END 2 */

	/* Infinite loop */
	/* USER CODE BEGIN WHILE */
	while (1) {
		MX_BlueNRG_2_Process();
		/* USER CODE END WHILE */

		/* USER CODE BEGIN 3 */
	}
	/* USER CODE END 3 */
}

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


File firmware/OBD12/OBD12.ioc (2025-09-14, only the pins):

Mcu.UserName=STM32G431KBTx
PA0.GPIO_Label=SPI1_IRQ
PA0.Signal=GPXTI0
PA1.GPIO_Label=BLE_NRST
PA1.Signal=GPIO_Output
PA10.Signal=USART1_RX
PA11.Signal=FDCAN1_RX
PA12.Signal=FDCAN1_TX
PA13.Signal=SYS_JTMS-SWDIO
PA14.Signal=SYS_JTCK-SWCLK
PA15.GPIO_Label=SPI1_CS
PA15.Signal=GPIO_Output
PA2.GPIO_Label=FDCAN_FAULT
PA2.Signal=GPXTI2
PA3.GPIO_Label=FDCAN_SILENT
PA3.Signal=GPIO_Output
PA4.GPIO_Label=HWCONF0
PA4.Signal=GPIO_Input
PA5.GPIO_Label=STATUS_LED_1
PA5.Signal=GPIO_Output
PA6.GPIO_Label=USB_REG_OUT
PA6.Signal=ADC2_IN3
PA7.GPIO_Label=CAN_REG_OUT
PA7.Signal=ADC2_IN4
PA8.GPIO_Label=HWCONF1
PA8.Signal=GPIO_Input
PA9.Signal=USART1_TX
PB0.GPIO_Label=STATUS_LED_2
PB0.Signal=GPIO_Output
PB3.Signal=SPI1_SCK
PB4.Signal=SPI1_MISO
PB5.Signal=SPI1_MOSI
PB6.GPIO_Label=USB_REG_ST
PB6.Signal=GPIO_Input
PB7.GPIO_Label=CAN_REG_ST
PB7.Signal=GPIO_Input
PF0-OSC_IN.Signal=RCC_OSC_IN
PF1-OSC_OUT.Signal=RCC_OSC_OUT

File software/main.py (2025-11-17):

import serial.tools.list_ports
import time

ports = serial.tools.list_ports.comports()

obd12_portinfo = None
for port in ports:
    if (port.vid == 0x0403 and port.pid == 0x6015):
        if (port.serial_number.startswith("OBD12_")):
            obd12_portinfo = port

if obd12_portinfo == None:
    print("Could not discover OBD12!")
    exit()

print(obd12_portinfo.serial_number, obd12_portinfo.device)
obd12_port = serial.Serial(
    port = obd12_portinfo.device, baudrate = 115200, bytesize=8, timeout=2, stopbits=serial.STOPBITS_ONE
)

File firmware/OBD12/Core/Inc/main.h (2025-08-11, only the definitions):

#define SPI1_IRQ_Pin GPIO_PIN_0
#define SPI1_IRQ_GPIO_Port GPIOA
#define SPI1_IRQ_EXTI_IRQn EXTI0_IRQn
#define BLE_NRST_Pin GPIO_PIN_1
#define BLE_NRST_GPIO_Port GPIOA
#define FDCAN_FAULT_Pin GPIO_PIN_2
#define FDCAN_FAULT_GPIO_Port GPIOA
#define FDCAN_FAULT_EXTI_IRQn EXTI2_IRQn
#define FDCAN_SILENT_Pin GPIO_PIN_3
#define FDCAN_SILENT_GPIO_Port GPIOA
#define HWCONF0_Pin GPIO_PIN_4
#define HWCONF0_GPIO_Port GPIOA
#define STATUS_LED_1_Pin GPIO_PIN_5
#define STATUS_LED_1_GPIO_Port GPIOA
#define USB_REG_OUT_Pin GPIO_PIN_6
#define USB_REG_OUT_GPIO_Port GPIOA
#define CAN_REG_OUT_Pin GPIO_PIN_7
#define CAN_REG_OUT_GPIO_Port GPIOA
#define STATUS_LED_2_Pin GPIO_PIN_0
#define STATUS_LED_2_GPIO_Port GPIOB
#define HWCONF1_Pin GPIO_PIN_8
#define HWCONF1_GPIO_Port GPIOA
#define SPI1_CS_Pin GPIO_PIN_15
#define SPI1_CS_GPIO_Port GPIOA
#define USB_REG_ST_Pin GPIO_PIN_6
#define USB_REG_ST_GPIO_Port GPIOB
#define CAN_REG_ST_Pin GPIO_PIN_7
#define CAN_REG_ST_GPIO_Port GPIOB

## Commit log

2025-08-08 add initial files
    [ble.kicad_sch, can.kicad_sch, pcb.kicad_pcb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]
2025-08-15 add slot for filter
    [can.kicad_sch, pcb.kicad_pcb, pcb.kicad_sch]
2026-10-05 remove pcb backups from git
2026-10-10 can rewrite: hw filter, rx ring, bus-off recovery
2026-10-15 new host protocol over usb, remove old uart code
2026-10-16 main loop, watchdog, power readings
2026-10-21 update pcb to kicad 10, fix 3d models, and begin enclosure

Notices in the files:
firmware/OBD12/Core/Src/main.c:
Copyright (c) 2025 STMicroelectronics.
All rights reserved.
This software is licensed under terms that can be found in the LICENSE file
